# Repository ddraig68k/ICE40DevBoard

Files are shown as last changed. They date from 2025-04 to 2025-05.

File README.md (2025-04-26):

# Lattice ICE40HX8K Development board

Intended as a development system for a software CPU computer design.

Includes:
16-bit VGA video
Audio output
512KB SRAM
FT232H interface for UART and device programming
MicroSD card
PS/2 Keyboard and mouse
Sega Megadrive joystick interface
3 push buttons
3 user LEDs
2 seven segment LEDs

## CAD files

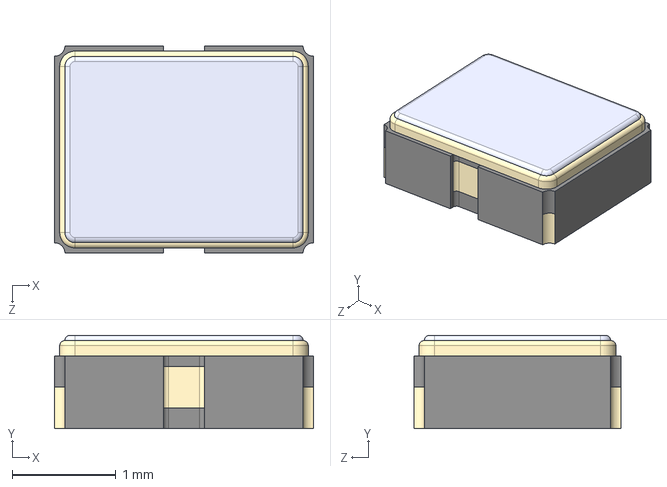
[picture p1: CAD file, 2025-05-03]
CAD/ECS-2520MV-120-BL-TR.STEP
2.50 x 0.9 x 2.00 mm

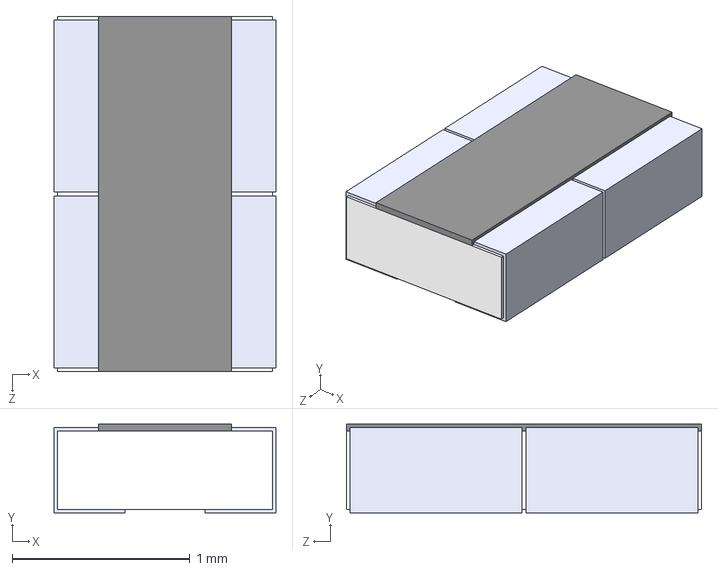
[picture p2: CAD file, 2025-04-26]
CAD/EXB-S8V391J.stp
1.25 x 0.5 x 2.00 mm

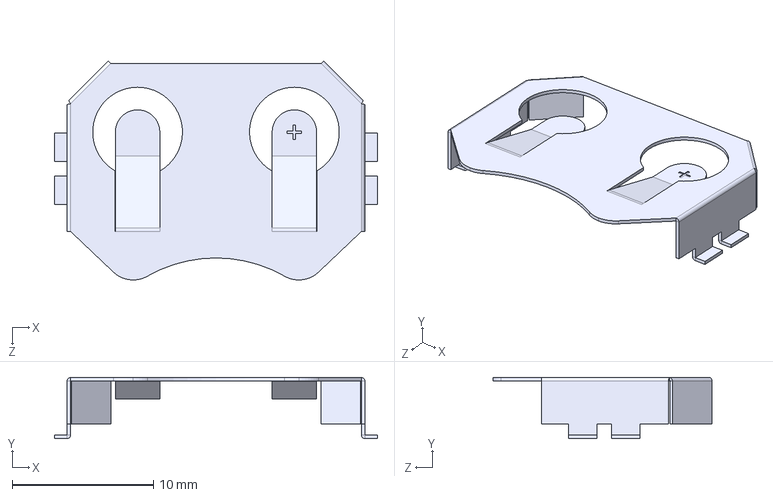
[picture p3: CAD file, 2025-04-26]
CAD/BAT-HLD-001.step
22.9 x 4.32 x 15.5 mm

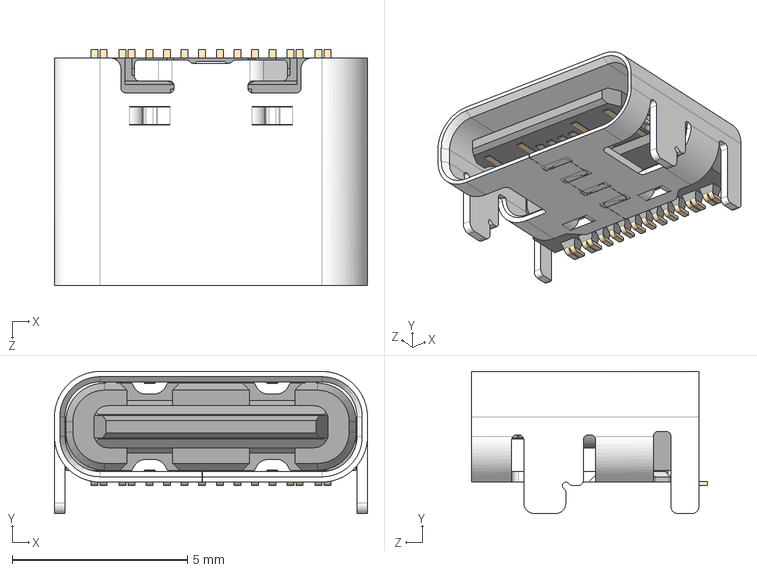
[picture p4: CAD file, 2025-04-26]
CAD/USB4215-03-A_revA.STEP
8.94 x 4.06 x 6.75 mm
HSG_ASM_1

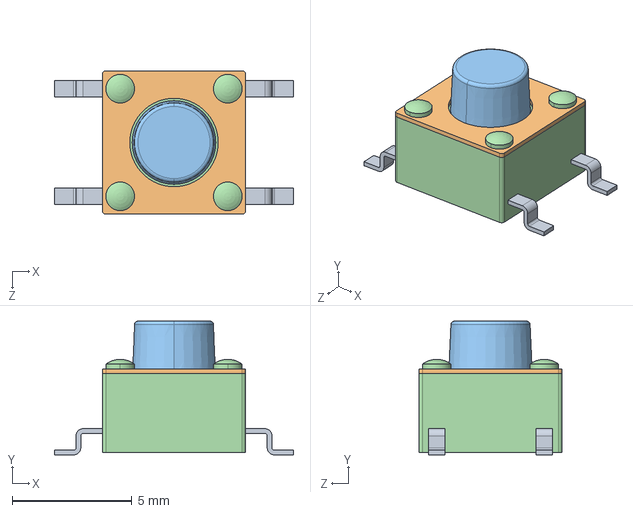
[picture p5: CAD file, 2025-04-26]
CAD/TS04-66-55-BK-100-SMT-TR.step
10.0 x 5.60 x 6.00 mm

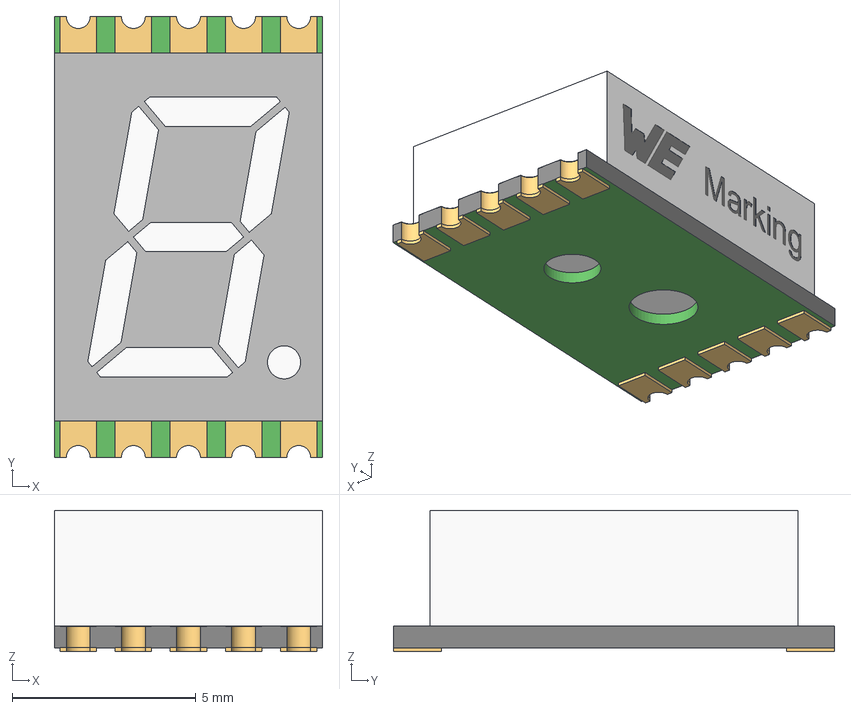
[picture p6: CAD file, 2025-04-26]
CAD/STP_157112x12x00+.stp
7.30 x 12.0 x 3.85 mm
PCB
Pins x 20
Chip

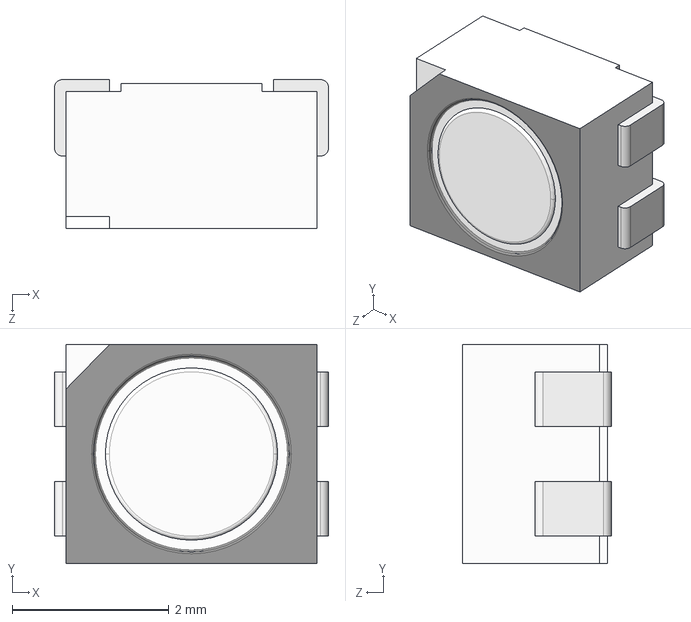
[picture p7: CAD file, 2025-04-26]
CAD/CLV1L-FKB-CJ1N1E1BB7B3B3.stp
3.50 x 2.80 x 1.90 mm

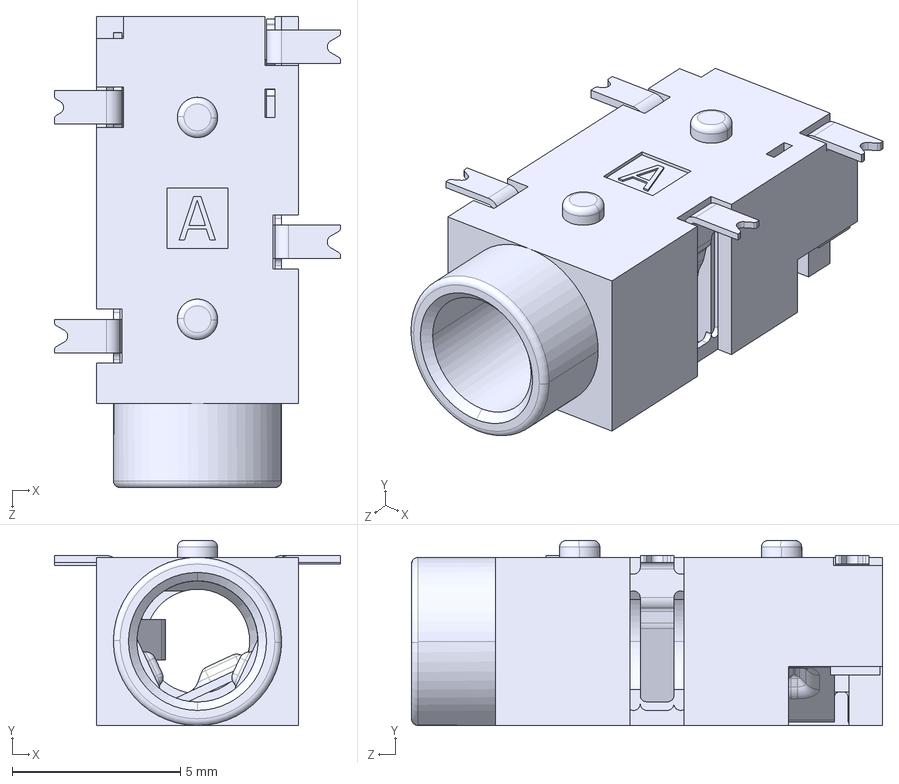
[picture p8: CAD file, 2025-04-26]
CAD/SJ2-35813B-SMT-TR.step
8.50 x 5.50 x 14.0 mm

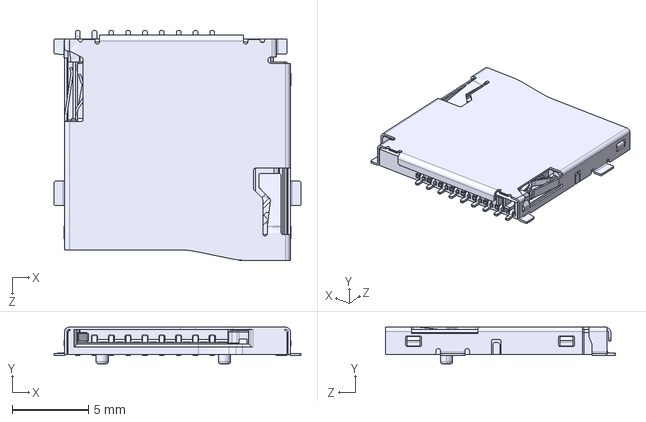
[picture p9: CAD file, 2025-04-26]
CAD/MSD-1-A.step
16.1 x 2.40 x 15.0 mm

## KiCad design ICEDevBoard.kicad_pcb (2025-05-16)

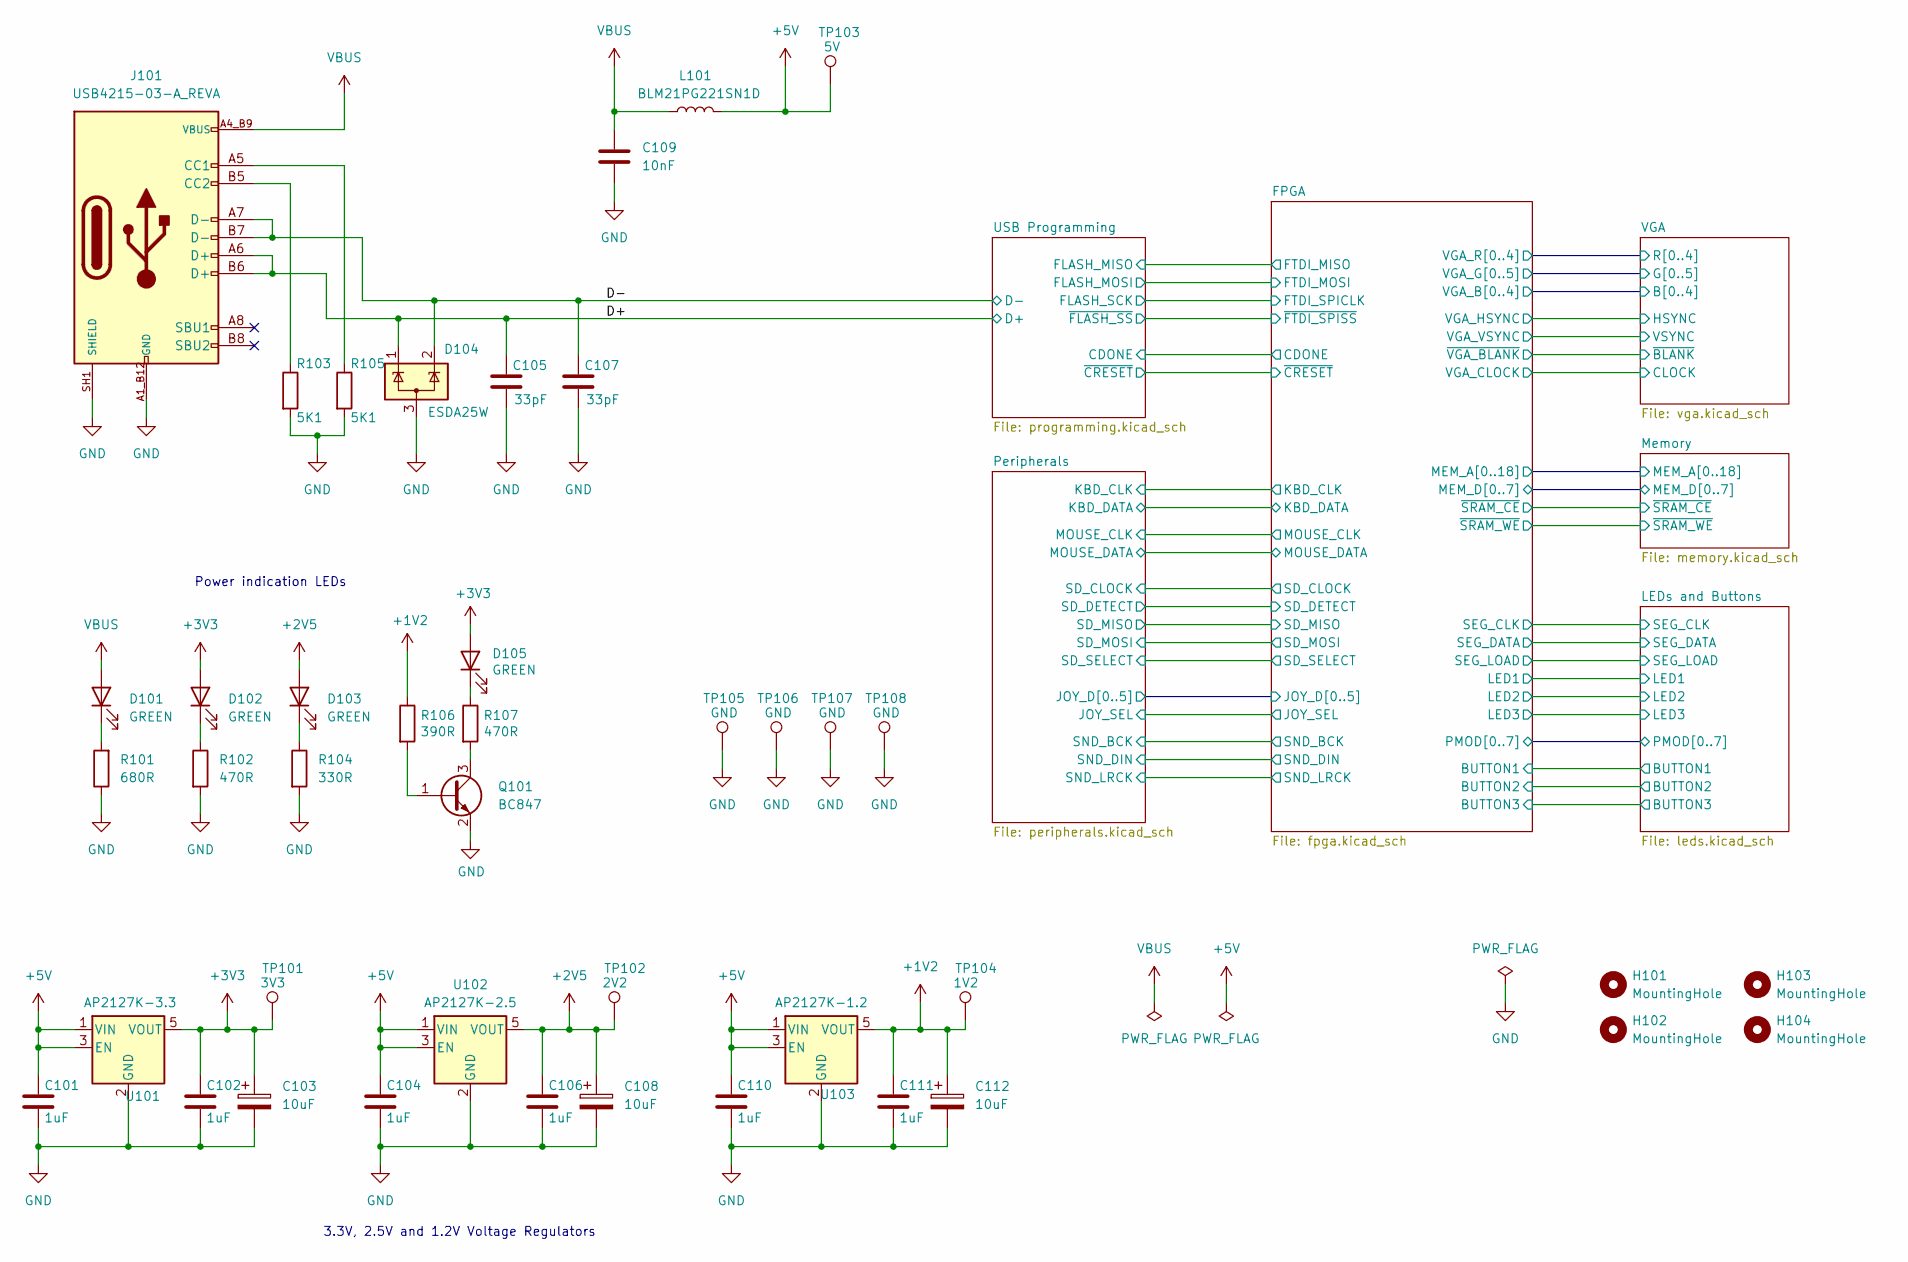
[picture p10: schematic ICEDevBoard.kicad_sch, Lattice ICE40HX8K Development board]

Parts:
C101, C102, C104, C106, C110, C111: 1uF; C_0805_2012Metric
C103, C108, C112: 10uF; CP_Elec_4x5.3
C105, C107: 33pF; C_0805_2012Metric
C109: 10nF; C_0805_2012Metric
D101, D102, D103, D105: GREEN; LED_1206_3216Metric
D104: ESDA25W; SOT-23-3
H101, H102, H103, H104: MountingHole; MountingHole_4.3mm_M4
J101: USB4215-03-A_REVA; GCT_USB4215-03-A_REVA; PARTREV A
L101: BLM21PG221SN1D; L_1206_3216Metric
Q101: BC847; SOT-23
R101: 680R; R_0805_2012Metric
R102, R107: 470R; R_0805_2012Metric
R103, R105: 5K1; R_0805_2012Metric
R104: 330R; R_0805_2012Metric
R106: 390R; R_0805_2012Metric
TP101: 3V3; TestPoint_Pad_D1.0mm
TP102: 2V2; TestPoint_Pad_D1.0mm
TP103: 5V; TestPoint_Pad_D1.0mm
TP104: 1V2; TestPoint_Pad_D1.0mm
TP105, TP106, TP107, TP108: GND; TestPoint_THTPad_D1.0mm_Drill0.5mm
U101: AP2127K-3.3; SOT-23-5
U102: AP2127K-2.5; SOT-23-5
U103: AP2127K-1.2; SOT-23-5

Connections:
+1V2: C111.1, C112.1, R106.1, TP104.1, U103.5 (VOUT); also elsewhere on the board
+2V5: C106.1, C108.1, D103.2 (A), TP102.1, U102.5 (VOUT); also elsewhere on the board
+3V3: C102.1, C103.1, D102.2 (A), D105.2 (A), TP101.1, U101.5 (VOUT); also elsewhere on the board
+5V: C101.1, C104.1, C110.1, L101.2, TP103.1, U101.1 (VIN), U101.3 (EN), U102.1 (VIN), U102.3 (EN), U103.1 (VIN), U103.3 (EN); also elsewhere on the board
/D+: C105.1, D104.1 (K), J101.A6 (D+), J101.B6 (D+); also elsewhere on the board
/D-: C107.1, D104.2 (K), J101.A7 (D-), J101.B7 (D-); also elsewhere on the board
GND: C101.2, C102.2, C103.2, C104.2, C105.2, C106.2, C107.2, C108.2, C109.2, C110.2, C111.2, C112.2, D104.3 (A), J101.A1_B12 (GND), J101.B1_A12 (GND), J101.SH1 (SHIELD), J101.SH2 (SHIELD), J101.SH3 (SHIELD), J101.SH4 (SHIELD), Q101.2 (E), R101.1, R102.2, R103.2, R104.2, R105.2, TP105.1, TP106.1, TP107.1, TP108.1, U101.2 (GND), U102.2 (GND), U103.2 (GND); also elsewhere on the board
unnamed: D101.1 (K), R101.2
unnamed: D102.1 (K), R102.1
unnamed: D103.1 (K), R104.1
unnamed: D105.1 (K), R107.1
unnamed: J101.A5 (CC1), R105.1
unnamed: J101.B5 (CC2), R103.1
unnamed: Q101.1 (B), R106.2
unnamed: Q101.3 (C), R107.2
VBUS: C109.1, D101.2 (A), J101.A4_B9 (VBUS), J101.B4_A9 (VBUS), L101.1

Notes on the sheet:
Power indication LEDs
3.3V, 2.5V and 1.2V Voltage Regulators

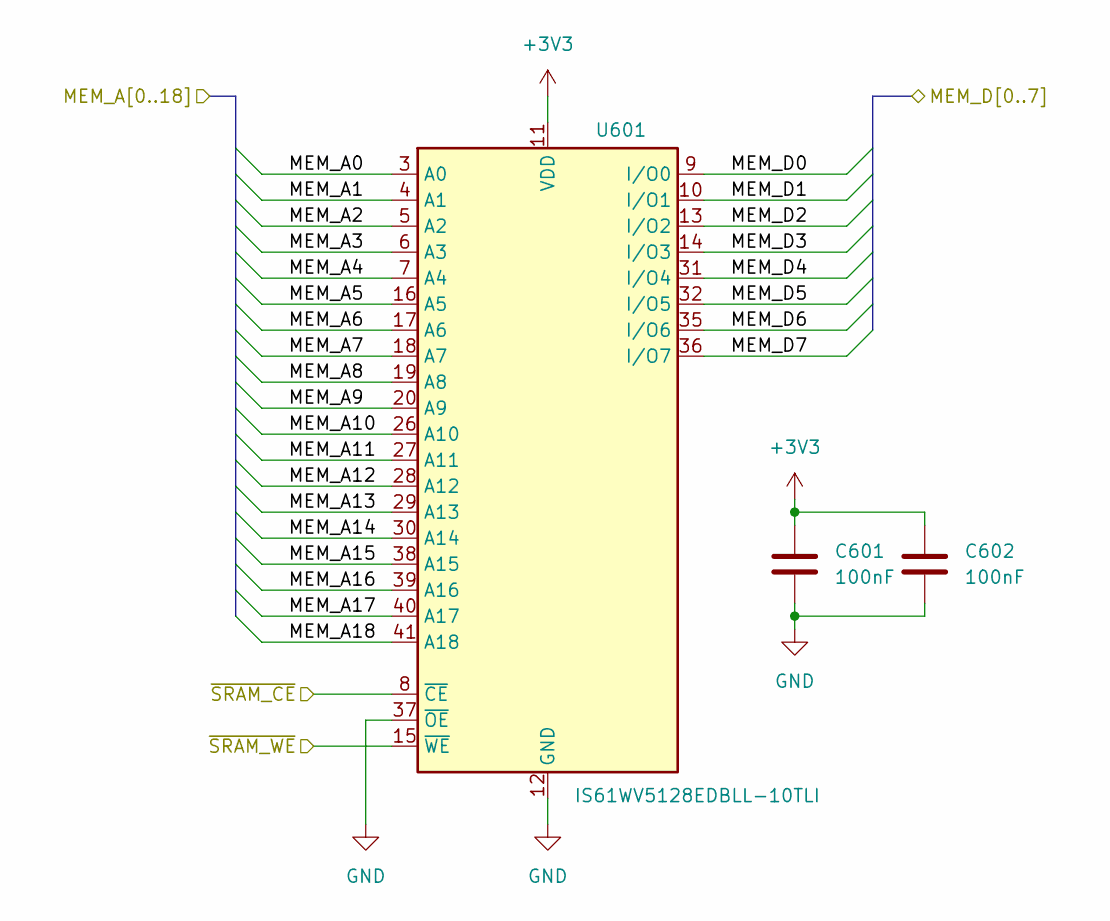
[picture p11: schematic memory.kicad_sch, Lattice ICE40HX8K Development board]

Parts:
C601, C602: 100nF; C_0805_2012Metric
U601: IS61WV5128EDBLL-10TLI; TSOP-II-44_10.16x18.41mm_P0.8mm

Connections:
+3V3: C601.1, C602.1, U601.11 (VDD), U601.33 (VDD); also elsewhere on the board
/FPGA/MEM_A0: U601.3 (A0); also elsewhere on the board
/FPGA/MEM_A1: U601.4 (A1); also elsewhere on the board
/FPGA/MEM_A2: U601.5 (A2); also elsewhere on the board
/FPGA/MEM_A3: U601.6 (A3); also elsewhere on the board
/FPGA/MEM_A4: U601.7 (A4); also elsewhere on the board
/FPGA/MEM_A5: U601.16 (A5); also elsewhere on the board
/FPGA/MEM_A6: U601.17 (A6); also elsewhere on the board
/FPGA/MEM_A7: U601.18 (A7); also elsewhere on the board
/FPGA/MEM_A8: U601.19 (A8); also elsewhere on the board
/FPGA/MEM_A9: U601.20 (A9); also elsewhere on the board
/FPGA/MEM_A10: U601.26 (A10); also elsewhere on the board
/FPGA/MEM_A11: U601.27 (A11); also elsewhere on the board
/FPGA/MEM_A12: U601.28 (A12); also elsewhere on the board
/FPGA/MEM_A13: U601.29 (A13); also elsewhere on the board
/FPGA/MEM_A14: U601.30 (A14); also elsewhere on the board
/FPGA/MEM_A15: U601.38 (A15); also elsewhere on the board
/FPGA/MEM_A16: U601.39 (A16); also elsewhere on the board
/FPGA/MEM_A17: U601.40 (A17); also elsewhere on the board
/FPGA/MEM_A18: U601.41 (A18); also elsewhere on the board
/FPGA/MEM_D0: U601.9 (I/O0); also elsewhere on the board
/FPGA/MEM_D1: U601.10 (I/O1); also elsewhere on the board
/FPGA/MEM_D2: U601.13 (I/O2); also elsewhere on the board
/FPGA/MEM_D3: U601.14 (I/O3); also elsewhere on the board
/FPGA/MEM_D4: U601.31 (I/O4); also elsewhere on the board
/FPGA/MEM_D5: U601.32 (I/O5); also elsewhere on the board
/FPGA/MEM_D6: U601.35 (I/O6); also elsewhere on the board
/FPGA/MEM_D7: U601.36 (I/O7); also elsewhere on the board
/FPGA/~SRAM_CE: U601.8 (~CE); also elsewhere on the board
/FPGA/~SRAM_WE: U601.15 (~WE); also elsewhere on the board
GND: C601.2, C602.2, U601.12 (GND), U601.34 (GND), U601.37 (~OE); also elsewhere on the board

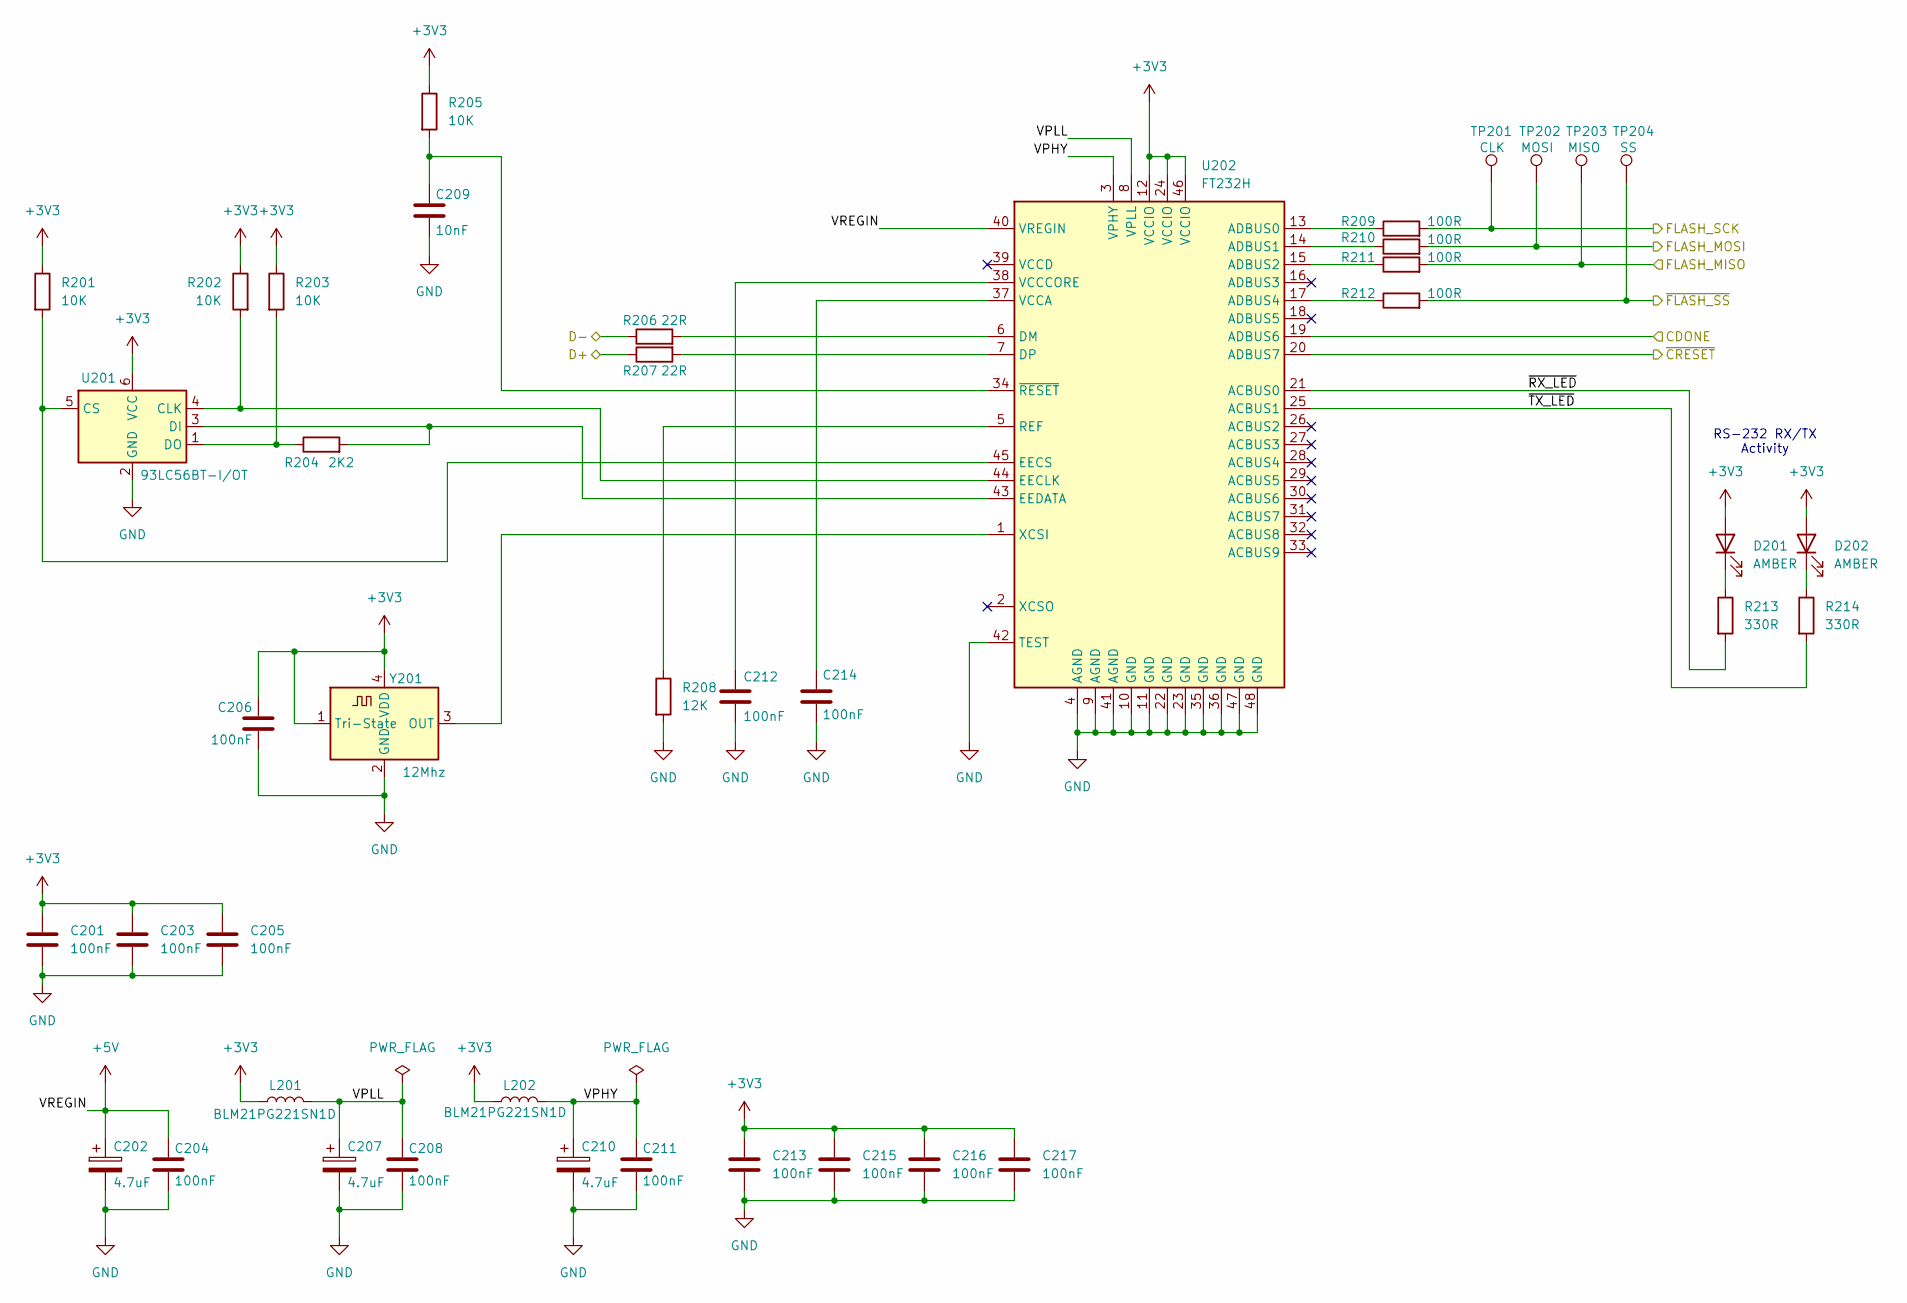
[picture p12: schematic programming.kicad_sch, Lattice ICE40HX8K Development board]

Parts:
C201, C203, C204, C205, C206, C208, C211, C212, C213, C214, C215, C216, C217: 100nF; C_0805_2012Metric
C202, C207, C210: 4.7uF; CP_Elec_4x5.3
C209: 10nF; C_0805_2012Metric
D201, D202: AMBER; LED_1206_3216Metric
L201, L202: BLM21PG221SN1D; L_1206_3216Metric
R201, R202, R203, R205: 10K; R_0805_2012Metric
R204: 2K2; R_0805_2012Metric
R206, R207: 22R; R_0805_2012Metric
R208: 12K; R_0805_2012Metric
R209, R210, R211, R212: 100R; R_0805_2012Metric
R213, R214: 330R; R_0805_2012Metric
TP201: CLK; TestPoint_Pad_D1.0mm
TP202: MOSI; TestPoint_Pad_D1.0mm
TP203: MISO; TestPoint_Pad_D1.0mm
TP204: SS; TestPoint_Pad_D1.0mm
U201: 93LC56BT-I/OT; SOT-23-6
U202: FT232H; LQFP-48_7x7mm_P0.5mm
Y201: 12Mhz; Oscillator_SMD_ECS_2520MV-xxx-xx-4Pin_2.5x2.0mm

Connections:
+3V3: C201.1, C203.1, C205.1, C206.1, C213.1, C215.1, C216.1, C217.1, D201.2 (A), D202.2 (A), L201.1, L202.1, R201.1, R202.1, R203.1, R205.1, U201.6 (VCC), U202.12 (VCCIO), U202.24 (VCCIO), U202.46 (VCCIO), Y201.1 (Tri-State), Y201.4 (VDD); also elsewhere on the board
+5V: C202.1, C204.1, U202.40 (VREGIN); also elsewhere on the board
/D+: R207.1; also elsewhere on the board
/D-: R206.1; also elsewhere on the board
/FPGA/CDONE: U202.19 (ADBUS6); also elsewhere on the board
/FPGA/FTDI_MISO: R211.2, TP203.1; also elsewhere on the board
/FPGA/FTDI_MOSI: R210.2, TP202.1; also elsewhere on the board
/FPGA/FTDI_SPICLK: R209.2, TP201.1; also elsewhere on the board
/FPGA/~CRESET: U202.20 (ADBUS7); also elsewhere on the board
/FPGA/~FTDI_SPISS: R212.2, TP204.1; also elsewhere on the board
/USB Programming/VPHY: C210.1, C211.1, L202.2, U202.3 (VPHY)
/USB Programming/VPLL: C207.1, C208.1, L201.2, U202.8 (VPLL)
/USB Programming/~RX_LED: R213.2, U202.21 (ACBUS0)
/USB Programming/~TX_LED: R214.2, U202.25 (ACBUS1)
GND: C201.2, C202.2, C203.2, C204.2, C205.2, C206.2, C207.2, C208.2, C209.2, C210.2, C211.2, C212.2, C213.2, C214.2, C215.2, C216.2, C217.2, R208.2, U201.2 (GND), U202.4 (AGND), U202.9 (AGND), U202.10 (GND), U202.11 (GND), U202.22 (GND), U202.23 (GND), U202.35 (GND), U202.36 (GND), U202.41 (AGND), U202.42 (TEST), U202.47 (GND), U202.48 (GND), Y201.2 (GND); also elsewhere on the board
unnamed: D201.1 (K), R213.1
unnamed: D202.1 (K), R214.1
unnamed: R202.2, U201.4 (CLK), U202.44 (EECLK)
unnamed: R201.2, U201.5 (CS), U202.45 (EECS)
unnamed: R204.2, U201.3 (DI), U202.43 (EEDATA)
unnamed: R203.2, R204.1, U201.1 (DO)
unnamed: R209.1, U202.13 (ADBUS0)
unnamed: R210.1, U202.14 (ADBUS1)
unnamed: R211.1, U202.15 (ADBUS2)
unnamed: R212.1, U202.17 (ADBUS4)
unnamed: R206.2, U202.6 (DM)
unnamed: R207.2, U202.7 (DP)
unnamed: R208.1, U202.5 (REF)
unnamed: C214.1, U202.37 (VCCA)
unnamed: C212.1, U202.38 (VCCCORE)
unnamed: U202.1 (XCSI), Y201.3 (OUT)
unnamed: C209.1, R205.2, U202.34 (~RESET)

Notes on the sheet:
RS-232 RX/TX Activity

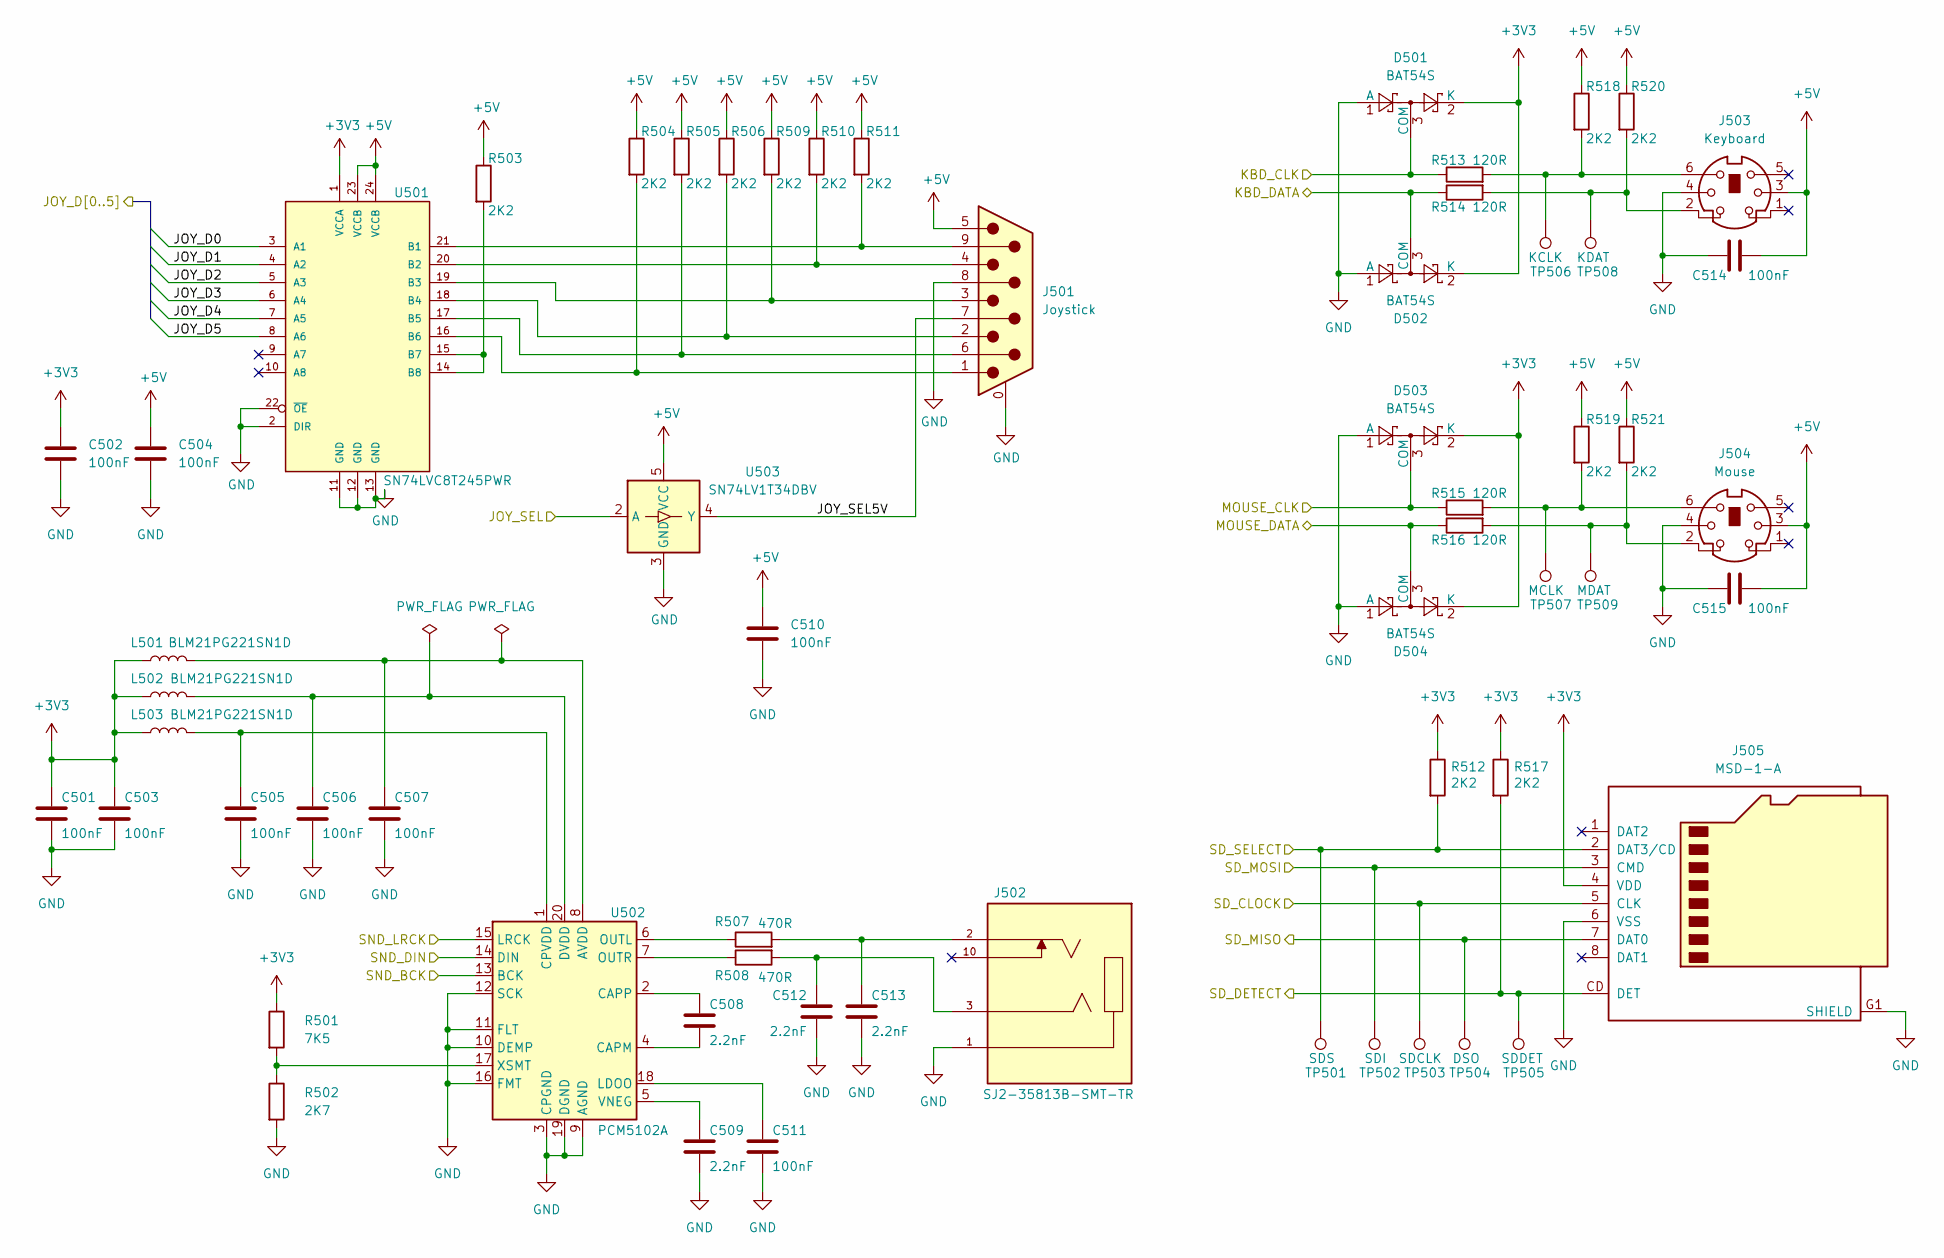
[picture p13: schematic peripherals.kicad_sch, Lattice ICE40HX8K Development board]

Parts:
C501, C502, C503, C504, C505, C506, C507, C510, C511, C514, C515: 100nF; C_0805_2012Metric
C508, C509, C512, C513: 2.2nF; C_0805_2012Metric
D501, D502, D503, D504: BAT54S; SOT-23
J501: Joystick; DSUB-9_Pins_Horizontal_P2.77x2.84mm_EdgePinOffset4.94mm_Hou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
J502: SJ2-35813B-SMT-TR; CUI_SJ2-35813B-SMT-TR
J503: Keyboard; MINI-DIN-6-FULL-SHIELD
J504: Mouse; MINI-DIN-6-FULL-SHIELD
J505: MSD-1-A; CUI_MSD-1-A
L501, L502, L503: BLM21PG221SN1D; L_1206_3216Metric
R501: 7K5; R_0805_2012Metric
R502: 2K7; R_0805_2012Metric
R503, R504, R505, R506, R509, R510, R511, R512, R517, R518, R519, R520, R521: 2K2; R_0805_2012Metric
R507, R508: 470R; R_0805_2012Metric
R513, R514, R515, R516: 120R; R_0805_2012Metric
TP501: SDS; TestPoint_Pad_D1.0mm
TP502: SDI; TestPoint_Pad_D1.0mm
TP503: SDCLK; TestPoint_Pad_D1.0mm
TP504: DSO; TestPoint_Pad_D1.0mm
TP505: SDDET; TestPoint_Pad_D1.0mm
TP506: KCLK; TestPoint_Pad_D1.0mm
TP507: MCLK; TestPoint_Pad_D1.0mm
TP508: KDAT; TestPoint_Pad_D1.0mm
TP509: MDAT; TestPoint_Pad_D1.0mm
U501: SN74LVC8T245PWR; SOP65P640X120-24N
U502: PCM5102A; TSSOP-20_4.4x6.5mm_P0.65mm
U503: SN74LV1T34DBV; SOT-23-5

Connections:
+3V3: C501.1, C502.1, C503.1, D501.2 (K), D502.2 (K), D503.2 (K), D504.2 (K), J505.4 (VDD), L501.1, L502.1, L503.1, R501.1, R512.1, R517.1, U501.1 (VCCA); also elsewhere on the board
+5V: C504.1, C510.1, C514.2, C515.2, J501.5, J503.3, J504.3, R503.1, R504.1, R505.1, R506.1, R509.1, R510.1, R511.1, R518.1, R519.1, R520.1, R521.1, U501.23 (VCCB), U501.24 (VCCB), U503.5 (VCC); also elsewhere on the board
/FPGA/JOY_D0: U501.3 (A1); also elsewhere on the board
/FPGA/JOY_D1: U501.4 (A2); also elsewhere on the board
/FPGA/JOY_D2: U501.5 (A3); also elsewhere on the board
/FPGA/JOY_D3: U501.6 (A4); also elsewhere on the board
/FPGA/JOY_D4: U501.7 (A5); also elsewhere on the board
/FPGA/JOY_D5: U501.8 (A6); also elsewhere on the board
/FPGA/JOY_SEL: U503.2 (A); also elsewhere on the board
/FPGA/KBD_CLK: D501.3 (COM), R513.1; also elsewhere on the board
/FPGA/KBD_DATA: D502.3 (COM), R514.1; also elsewhere on the board
/FPGA/MOUSE_CLK: D503.3 (COM), R515.1; also elsewhere on the board
/FPGA/MOUSE_DATA: D504.3 (COM), R516.1; also elsewhere on the board
/FPGA/SD_CLOCK: J505.5 (CLK), TP503.1; also elsewhere on the board
/FPGA/SD_DETECT: J505.CD (DET), R517.2, TP505.1; also elsewhere on the board
/FPGA/SD_MISO: J505.7 (DAT0), TP504.1; also elsewhere on the board
/FPGA/SD_MOSI: J505.3 (CMD), TP502.1; also elsewhere on the board
/FPGA/SD_SELECT: J505.2 (DAT3/CD), R512.2, TP501.1; also elsewhere on the board
/FPGA/SND_BCK: U502.13 (BCK); also elsewhere on the board
/FPGA/SND_DIN: U502.14 (DIN); also elsewhere on the board
/FPGA/SND_LRCK: U502.15 (LRCK); also elsewhere on the board
/Peripherals/JOY_SEL5V: J501.7, U503.4 (Y)
GND: C501.2, C502.2, C503.2, C504.2, C505.2, C506.2, C507.2, C509.2, C510.2, C511.2, C512.2, C513.2, C514.1, C515.1, D501.1 (A), D502.1 (A), D503.1 (A), D504.1 (A), J501.0 (PAD), J501.8, J502.1, J503.4, J504.4, J505.6 (VSS), J505.G1 (SHIELD), J505.G2 (SHIELD), J505.G3 (SHIELD), J505.G4 (SHIELD), R502.2, U501.2 (DIR), U501.11 (GND), U501.12 (GND), U501.13 (GND), U501.22 (~OE), U502.3 (CPGND), U502.9 (AGND), U502.10 (DEMP), U502.11 (FLT), U502.12 (SCK), U502.16 (FMT), U502.19 (DGND), U503.3 (GND); also elsewhere on the board
unnamed: C512.1, J502.3, R508.2
unnamed: C513.1, J502.2, R507.2
unnamed: J503.2, R514.2, R520.2, TP508.1
unnamed: J503.6, R513.2, R518.2, TP506.1
unnamed: J504.2, R516.2, R521.2, TP509.1
unnamed: J504.6, R515.2, R519.2, TP507.1
unnamed: J501.9, R511.2, U501.21 (B1)
unnamed: J501.4, R510.2, U501.20 (B2)
unnamed: J501.3, R509.2, U501.19 (B3)
unnamed: J501.2, R506.2, U501.18 (B4)
unnamed: J501.6, R505.2, U501.17 (B5)
unnamed: J501.1, R504.2, U501.16 (B6)
unnamed: R503.2, U501.14 (B8), U501.15 (B7)
unnamed: C507.1, L501.2, U502.8 (AVDD)
unnamed: C508.2, U502.4 (CAPM)
unnamed: C508.1, U502.2 (CAPP)
unnamed: C505.1, L503.2, U502.1 (CPVDD)
unnamed: C506.1, L502.2, U502.20 (DVDD)
unnamed: C511.1, U502.18 (LDOO)
unnamed: R507.1, U502.6 (OUTL)
unnamed: R508.1, U502.7 (OUTR)
unnamed: C509.1, U502.5 (VNEG)
unnamed: R501.2, R502.1, U502.17 (XSMT)

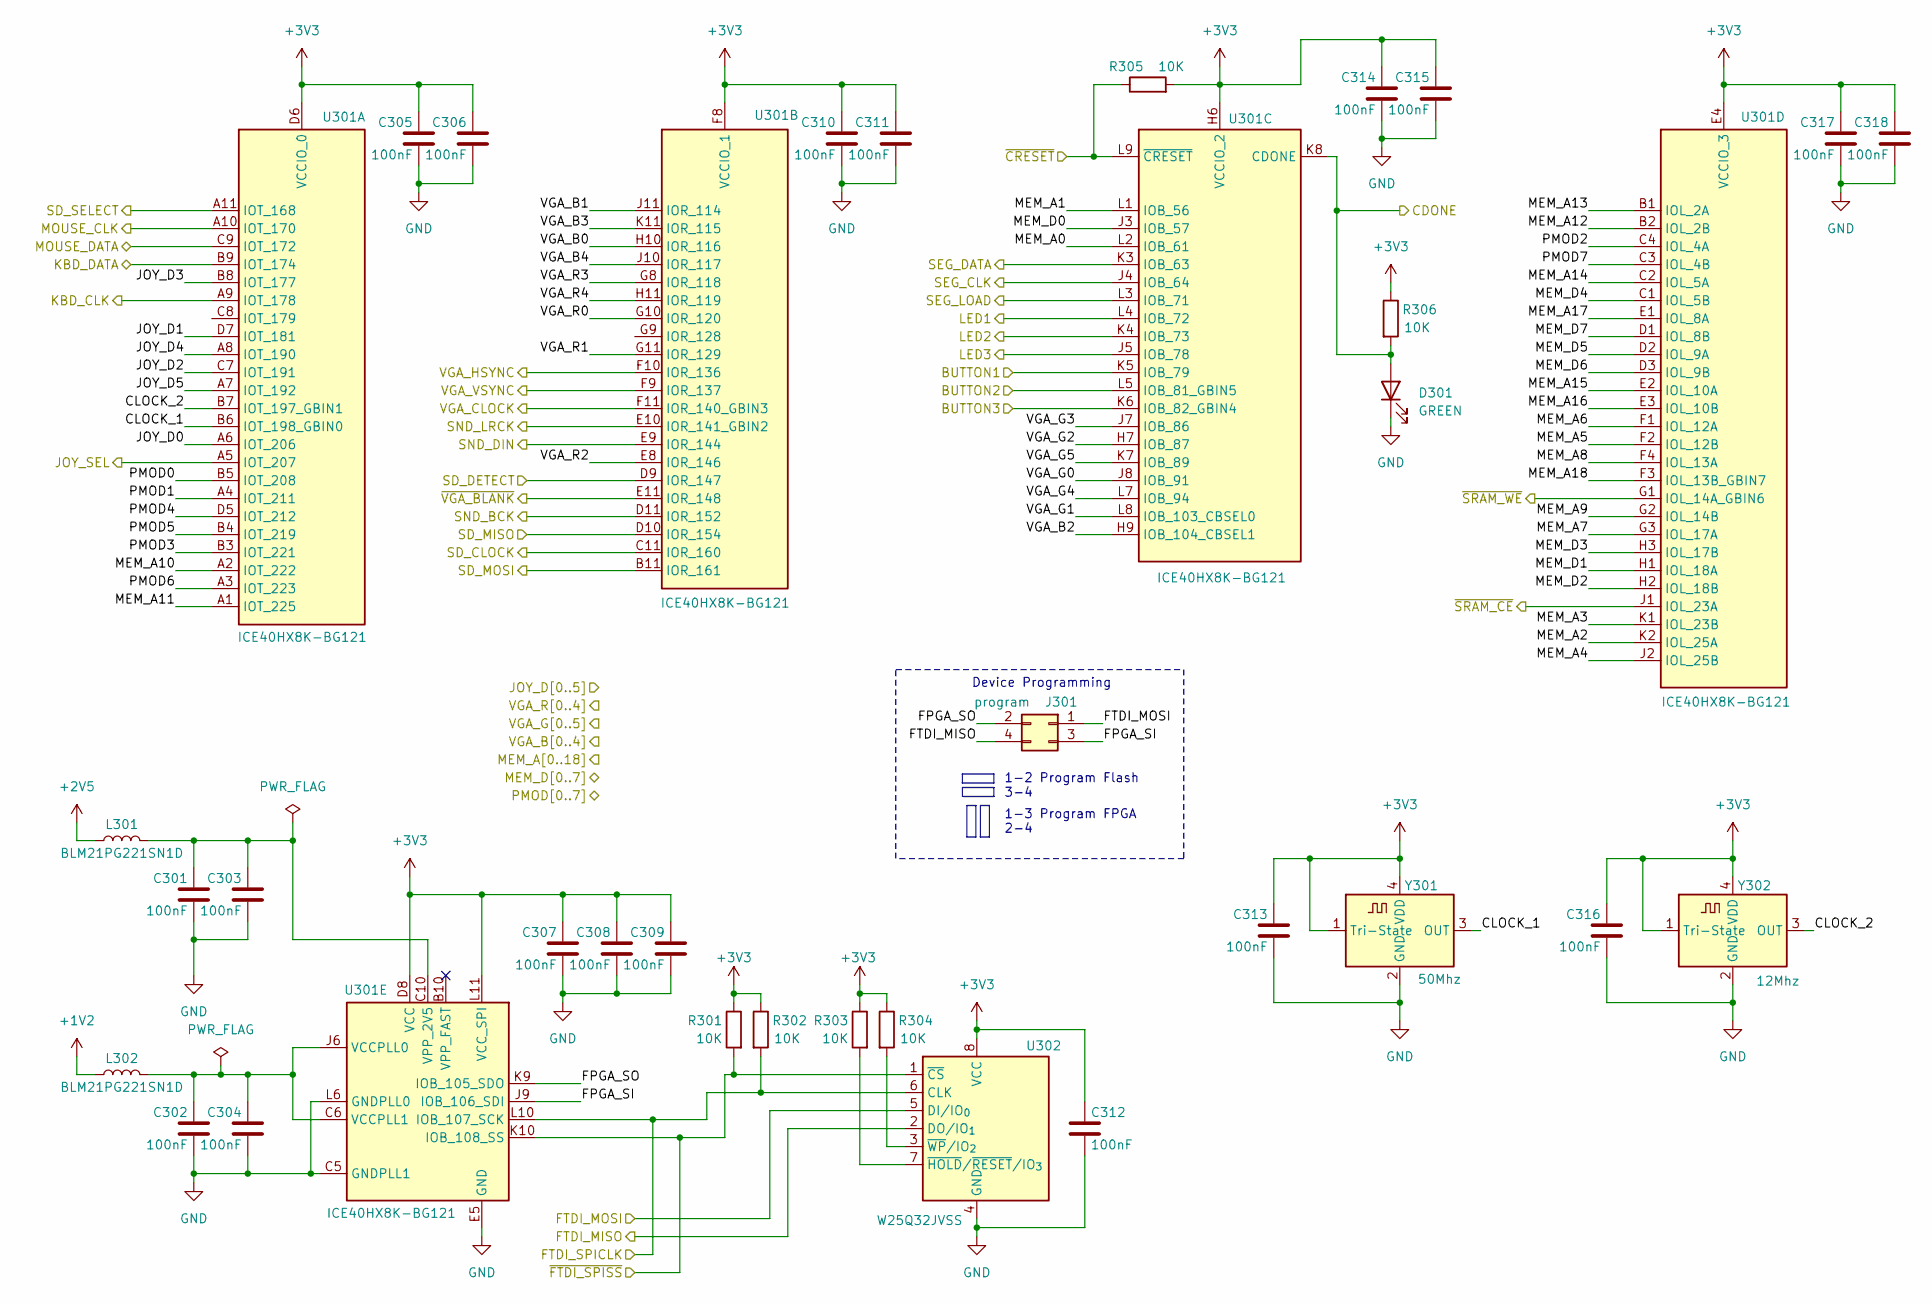
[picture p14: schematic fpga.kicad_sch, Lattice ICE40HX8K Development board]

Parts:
C301, C302, C303, C304, C305, C306, C307, C308, C309, C310, C311, C312, C313, C314, C315, C316, C317, C318: 100nF; C_0603_1608Metric
D301: GREEN; LED_1206_3216Metric
J301: program; PinSocket_2x02_P2.54mm_Vertical
L301, L302: BLM21PG221SN1D; L_1206_3216Metric
R301, R302, R303, R304, R305, R306: 10K; R_0805_2012Metric
U301: ICE40HX8K-BG121; BGA-121_9.0x9.0mm_Layout11x11_P0.8mm_Ball0.4mm_Pad0.35mm_NS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
U302: W25Q32JVSS; SOIC-8_5.3x5.3mm_P1.27mm
Y301: 50Mhz; Oscillator_SMD_ECS_2520MV-xxx-xx-4Pin_2.5x2.0mm
Y302: 12Mhz; Oscillator_SMD_ECS_2520MV-xxx-xx-4Pin_2.5x2.0mm

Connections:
+1V2: L302.1; also elsewhere on the board
+2V5: L301.1; also elsewhere on the board
+3V3: C305.1, C306.1, C307.1, C308.1, C309.1, C310.1, C311.1, C312.1, C313.1, C314.1, C315.1, C316.1, C317.1, C318.1, R301.1, R302.1, R303.1, R304.1, R305.2, R306.1, U301.D4 (VCC), U301.D6 (VCCIO_0), U301.D8 (VCC), U301.E4 (VCCIO_3), U301.F8 (VCCIO_1), U301.G4 (VCCIO_3), U301.H4 (VCC), U301.H6 (VCCIO_2), U301.H8 (VCC), U301.L11 (VCC_SPI), U302.8 (VCC), Y301.1 (Tri-State), Y301.4 (VDD), Y302.1 (Tri-State), Y302.4 (VDD); also elsewhere on the board
/FPGA/BUTTON1: U301.K5 (IOB_79); also elsewhere on the board
/FPGA/BUTTON2: U301.L5 (IOB_81_GBIN5); also elsewhere on the board
/FPGA/BUTTON3: U301.K6 (IOB_82_GBIN4); also elsewhere on the board
/FPGA/CDONE: D301.2 (A), R306.2, U301.K8 (CDONE); also elsewhere on the board
/FPGA/CLOCK_1: U301.B6 (IOT_198_GBIN0), Y301.3 (OUT)
/FPGA/CLOCK_2: U301.B7 (IOT_197_GBIN1), Y302.3 (OUT)
/FPGA/FPGA_SI: J301.3, U301.J9 (IOB_106_SDI)
/FPGA/FPGA_SO: J301.2, U301.K9 (IOB_105_SDO)
/FPGA/FTDI_MISO: J301.4, U302.2 (DO/IO_{1}); also elsewhere on the board
/FPGA/FTDI_MOSI: J301.1, U302.5 (DI/IO_{0}); also elsewhere on the board
/FPGA/FTDI_SPICLK: R302.2, U301.L10 (IOB_107_SCK), U302.6 (CLK); also elsewhere on the board
/FPGA/JOY_D0: U301.A6 (IOT_206); also elsewhere on the board
/FPGA/JOY_D1: U301.D7 (IOT_181); also elsewhere on the board
/FPGA/JOY_D2: U301.C7 (IOT_191); also elsewhere on the board
/FPGA/JOY_D3: U301.B8 (IOT_177); also elsewhere on the board
/FPGA/JOY_D4: U301.A8 (IOT_190); also elsewhere on the board
/FPGA/JOY_D5: U301.A7 (IOT_192); also elsewhere on the board
/FPGA/JOY_SEL: U301.A5 (IOT_207); also elsewhere on the board
/FPGA/KBD_CLK: U301.A9 (IOT_178); also elsewhere on the board
/FPGA/KBD_DATA: U301.B9 (IOT_174); also elsewhere on the board
/FPGA/LED1: U301.L4 (IOB_72); also elsewhere on the board
/FPGA/LED2: U301.K4 (IOB_73); also elsewhere on the board
/FPGA/LED3: U301.J5 (IOB_78); also elsewhere on the board
/FPGA/MEM_A0: U301.L2 (IOB_61); also elsewhere on the board
/FPGA/MEM_A1: U301.L1 (IOB_56); also elsewhere on the board
/FPGA/MEM_A2: U301.K2 (IOL_25A); also elsewhere on the board
/FPGA/MEM_A3: U301.K1 (IOL_23B); also elsewhere on the board
/FPGA/MEM_A4: U301.J2 (IOL_25B); also elsewhere on the board
/FPGA/MEM_A5: U301.F2 (IOL_12B); also elsewhere on the board
/FPGA/MEM_A6: U301.F1 (IOL_12A); also elsewhere on the board
/FPGA/MEM_A7: U301.G3 (IOL_17A); also elsewhere on the board
/FPGA/MEM_A8: U301.F4 (IOL_13A); also elsewhere on the board
/FPGA/MEM_A9: U301.G2 (IOL_14B); also elsewhere on the board
/FPGA/MEM_A10: U301.A2 (IOT_222); also elsewhere on the board
/FPGA/MEM_A11: U301.A1 (IOT_225); also elsewhere on the board
/FPGA/MEM_A12: U301.B2 (IOL_2B); also elsewhere on the board
/FPGA/MEM_A13: U301.B1 (IOL_2A); also elsewhere on the board
/FPGA/MEM_A14: U301.C2 (IOL_5A); also elsewhere on the board
/FPGA/MEM_A15: U301.E2 (IOL_10A); also elsewhere on the board
/FPGA/MEM_A16: U301.E3 (IOL_10B); also elsewhere on the board
/FPGA/MEM_A17: U301.E1 (IOL_8A); also elsewhere on the board
/FPGA/MEM_A18: U301.F3 (IOL_13B_GBIN7); also elsewhere on the board
/FPGA/MEM_D0: U301.J3 (IOB_57); also elsewhere on the board
/FPGA/MEM_D1: U301.H1 (IOL_18A); also elsewhere on the board
/FPGA/MEM_D2: U301.H2 (IOL_18B); also elsewhere on the board
/FPGA/MEM_D3: U301.H3 (IOL_17B); also elsewhere on the board
/FPGA/MEM_D4: U301.C1 (IOL_5B); also elsewhere on the board
/FPGA/MEM_D5: U301.D2 (IOL_9A); also elsewhere on the board
/FPGA/MEM_D6: U301.D3 (IOL_9B); also elsewhere on the board
/FPGA/MEM_D7: U301.D1 (IOL_8B); also elsewhere on the board
/FPGA/MOUSE_CLK: U301.A10 (IOT_170); also elsewhere on the board
/FPGA/MOUSE_DATA: U301.C9 (IOT_172); also elsewhere on the board
/FPGA/PMOD0: U301.B5 (IOT_208); also elsewhere on the board
/FPGA/PMOD1: U301.A4 (IOT_211); also elsewhere on the board
/FPGA/PMOD2: U301.C4 (IOL_4A); also elsewhere on the board
/FPGA/PMOD3: U301.B3 (IOT_221); also elsewhere on the board
/FPGA/PMOD4: U301.D5 (IOT_212); also elsewhere on the board
/FPGA/PMOD5: U301.B4 (IOT_219); also elsewhere on the board
/FPGA/PMOD6: U301.A3 (IOT_223); also elsewhere on the board
/FPGA/PMOD7: U301.C3 (IOL_4B); also elsewhere on the board
/FPGA/SD_CLOCK: U301.C11 (IOR_160); also elsewhere on the board
/FPGA/SD_DETECT: U301.D9 (IOR_147); also elsewhere on the board
/FPGA/SD_MISO: U301.D10 (IOR_154); also elsewhere on the board
/FPGA/SD_MOSI: U301.B11 (IOR_161); also elsewhere on the board
/FPGA/SD_SELECT: U301.A11 (IOT_168); also elsewhere on the board
/FPGA/SEG_CLK: U301.J4 (IOB_64); also elsewhere on the board
/FPGA/SEG_DATA: U301.K3 (IOB_63); also elsewhere on the board
/FPGA/SEG_LOAD: U301.L3 (IOB_71); also elsewhere on the board
/FPGA/SND_BCK: U301.D11 (IOR_152); also elsewhere on the board
/FPGA/SND_DIN: U301.E9 (IOR_144); also elsewhere on the board
/FPGA/SND_LRCK: U301.E10 (IOR_141_GBIN2); also elsewhere on the board
/FPGA/VGA_B0: U301.H10 (IOR_116); also elsewhere on the board
/FPGA/VGA_B1: U301.J11 (IOR_114); also elsewhere on the board
/FPGA/VGA_B2: U301.H9 (IOB_104_CBSEL1); also elsewhere on the board
/FPGA/VGA_B3: U301.K11 (IOR_115); also elsewhere on the board
/FPGA/VGA_B4: U301.J10 (IOR_117); also elsewhere on the board
/FPGA/VGA_CLOCK: U301.F11 (IOR_140_GBIN3); also elsewhere on the board
/FPGA/VGA_G0: U301.J8 (IOB_91); also elsewhere on the board
/FPGA/VGA_G1: U301.L8 (IOB_103_CBSEL0); also elsewhere on the board
/FPGA/VGA_G2: U301.H7 (IOB_87); also elsewhere on the board
/FPGA/VGA_G3: U301.J7 (IOB_86); also elsewhere on the board
/FPGA/VGA_G4: U301.L7 (IOB_94); also elsewhere on the board
/FPGA/VGA_G5: U301.K7 (IOB_89); also elsewhere on the board
/FPGA/VGA_HSYNC: U301.F10 (IOR_136); also elsewhere on the board
/FPGA/VGA_R0: U301.G10 (IOR_120); also elsewhere on the board
/FPGA/VGA_R1: U301.G11 (IOR_129); also elsewhere on the board
/FPGA/VGA_R2: U301.E8 (IOR_146); also elsewhere on the board
/FPGA/VGA_R3: U301.G8 (IOR_118); also elsewhere on the board
/FPGA/VGA_R4: U301.H11 (IOR_119); also elsewhere on the board
/FPGA/VGA_VSYNC: U301.F9 (IOR_137); also elsewhere on the board
/FPGA/~CRESET: R305.1, U301.L9 (~CRESET); also elsewhere on the board
/FPGA/~FTDI_SPISS: R301.2, U301.K10 (IOB_108_SS), U302.1 (~CS); also elsewhere on the board
/FPGA/~SRAM_CE: U301.J1 (IOL_23A); also elsewhere on the board
/FPGA/~SRAM_WE: U301.G1 (IOL_14A_GBIN6); also elsewhere on the board
/FPGA/~VGA_BLANK: U301.E11 (IOR_148); also elsewhere on the board
GND: C301.2, C302.2, C303.2, C304.2, C305.2, C306.2, C307.2, C308.2, C309.2, C310.2, C311.2, C312.2, C313.2, C314.2, C315.2, C316.2, C317.2, C318.2, D301.1 (K), U301.C5 (GNDPLL1), U301.E5 (GND), U301.E6 (GND), U301.E7 (GND), U301.F5 (GND), U301.F6 (GND), U301.F7 (GND), U301.G5 (GND), U301.G6 (GND), U301.G7 (GND), U301.H5 (GND), U301.L6 (GNDPLL0), U302.4 (GND), Y301.2 (GND), Y302.2 (GND); also elsewhere on the board
unnamed: C302.1, C304.1, L302.2, U301.C6 (VCCPLL1), U301.J6 (VCCPLL0)
unnamed: C301.1, C303.1, L301.2, U301.C10 (VPP_2V5)
unnamed: R303.2, U302.7 (~HOLD/~RESET/IO_{3})
unnamed: R304.2, U302.3 (~WP/IO_{2})

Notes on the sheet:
1-2 Program Flash 3-4
1-3 Program FPGA 2-4
Device Programming

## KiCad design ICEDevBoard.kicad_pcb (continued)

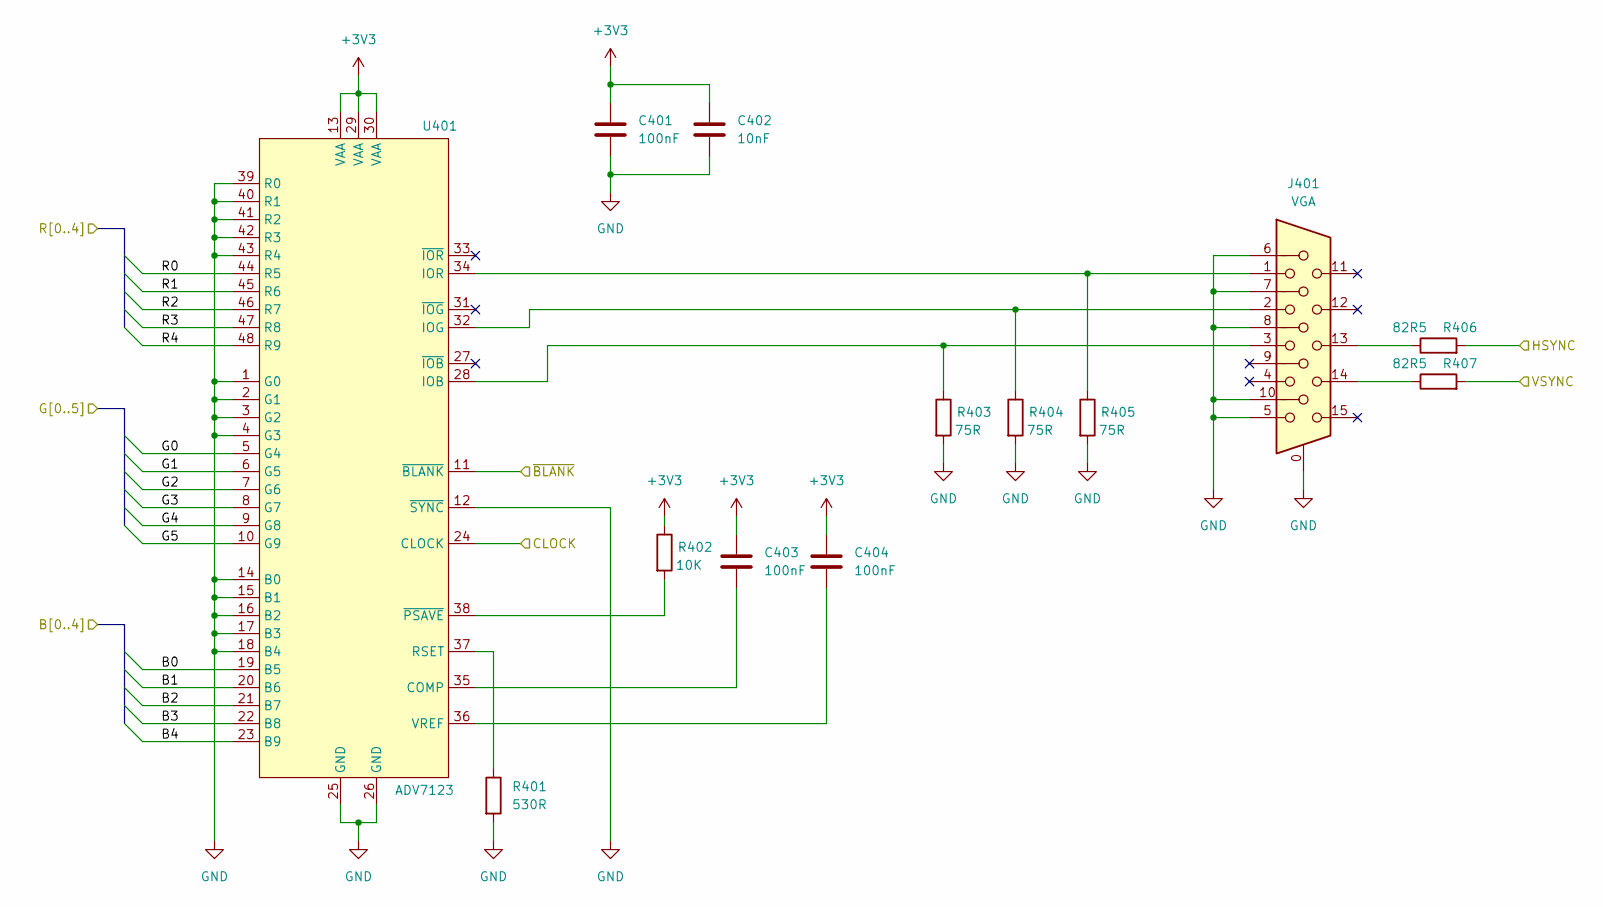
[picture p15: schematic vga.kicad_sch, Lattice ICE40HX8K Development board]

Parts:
C401, C403, C404: 100nF; C_0805_2012Metric
C402: 10nF; C_0805_2012Metric
J401: VGA; DSUB-15-HD_Socket_Horizontal_P2.29x2.54mm_EdgePinOffset8.35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
R401: 530R; R_0805_2012Metric
R402: 10K; R_0805_2012Metric
R403, R404, R405: 75R; R_0805_2012Metric
R406, R407: 82R5; R_0805_2012Metric
U401: ADV7123; LQFP-48_7x7mm_P0.5mm

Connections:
+3V3: C401.1, C402.1, C403.1, C404.1, R402.1, U401.13 (VAA), U401.29 (VAA), U401.30 (VAA); also elsewhere on the board
/FPGA/VGA_B0: U401.19 (B5); also elsewhere on the board
/FPGA/VGA_B1: U401.20 (B6); also elsewhere on the board
/FPGA/VGA_B2: U401.21 (B7); also elsewhere on the board
/FPGA/VGA_B3: U401.22 (B8); also elsewhere on the board
/FPGA/VGA_B4: U401.23 (B9); also elsewhere on the board
/FPGA/VGA_CLOCK: U401.24 (CLOCK); also elsewhere on the board
/FPGA/VGA_G0: U401.5 (G4); also elsewhere on the board
/FPGA/VGA_G1: U401.6 (G5); also elsewhere on the board
/FPGA/VGA_G2: U401.7 (G6); also elsewhere on the board
/FPGA/VGA_G3: U401.8 (G7); also elsewhere on the board
/FPGA/VGA_G4: U401.9 (G8); also elsewhere on the board
/FPGA/VGA_G5: U401.10 (G9); also elsewhere on the board
/FPGA/VGA_HSYNC: R406.2; also elsewhere on the board
/FPGA/VGA_R0: U401.44 (R5); also elsewhere on the board
/FPGA/VGA_R1: U401.45 (R6); also elsewhere on the board
/FPGA/VGA_R2: U401.46 (R7); also elsewhere on the board
/FPGA/VGA_R3: U401.47 (R8); also elsewhere on the board
/FPGA/VGA_R4: U401.48 (R9); also elsewhere on the board
/FPGA/VGA_VSYNC: R407.2; also elsewhere on the board
/FPGA/~VGA_BLANK: U401.11 (~BLANK); also elsewhere on the board
GND: C401.2, C402.2, J401.0, J401.5, J401.6, J401.7, J401.8, J401.10, R401.2, R403.2, R404.2, R405.2, U401.1 (G0), U401.2 (G1), U401.3 (G2), U401.4 (G3), U401.12 (~SYNC), U401.14 (B0), U401.15 (B1), U401.16 (B2), U401.17 (B3), U401.18 (B4), U401.25 (GND), U401.26 (GND), U401.39 (R0), U401.40 (R1), U401.41 (R2), U401.42 (R3), U401.43 (R4); also elsewhere on the board
unnamed: J401.13, R406.1
unnamed: J401.14, R407.1
unnamed: C403.2, U401.35 (COMP)
unnamed: J401.3, R403.1, U401.28 (IOB)
unnamed: J401.2, R404.1, U401.32 (IOG)
unnamed: J401.1, R405.1, U401.34 (IOR)
unnamed: R401.1, U401.37 (RSET)
unnamed: C404.2, U401.36 (VREF)
unnamed: R402.2, U401.38 (~PSAVE)

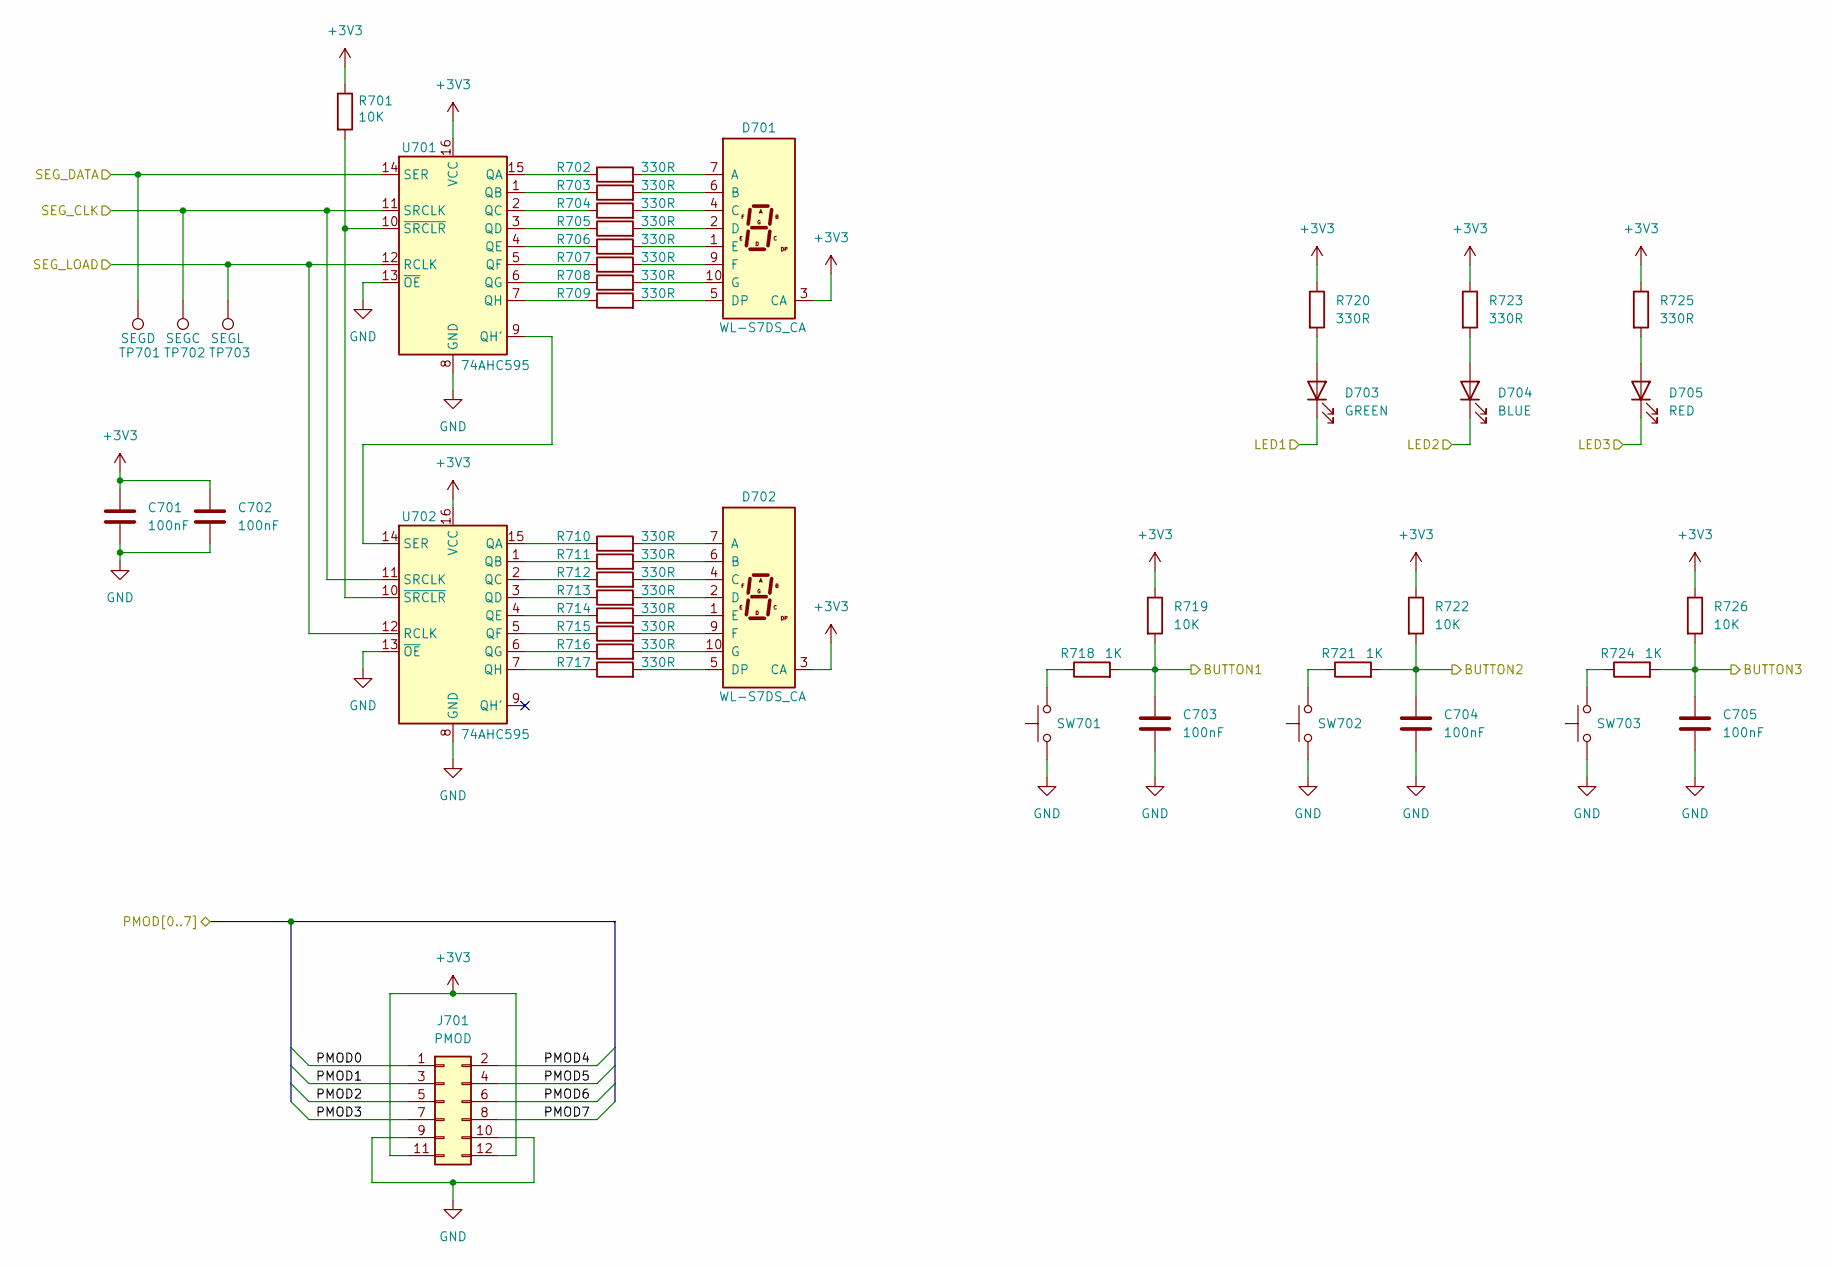
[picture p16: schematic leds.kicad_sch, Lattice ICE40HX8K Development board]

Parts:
C701, C702, C703, C704, C705: 100nF; C_0805_2012Metric
D701, D702: WL-S7DS_CA; WL-S7DS_0.3INCH
D703: GREEN; LED_1206_3216Metric
D704: BLUE; LED_1206_3216Metric
D705: RED; LED_1206_3216Metric
J701: PMOD; PinSocket_2x06_P2.54mm_Vertical
R701, R719, R722, R726: 10K; R_0805_2012Metric
R702, R703, R704, R705, R706, R707, R708, R709, R710, R711, R712, R713, R714, R715, R716, R717, R720, R723, R725: 330R; R_0805_2012Metric
R718, R721, R724: 1K; R_0805_2012Metric
SW701, SW702, SW703: SW_Push; SW_PUSH_6mm_H4.3mm
TP701: SEGD; TestPoint_Pad_D1.0mm
TP702: SEGC; TestPoint_Pad_D1.0mm
TP703: SEGL; TestPoint_Pad_D1.0mm
U701, U702: 74AHC595; SO-16_3.9x9.9mm_P1.27mm

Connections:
+3V3: C701.1, C702.1, D701.3 (CA), D702.3 (CA), J701.11, J701.12, R701.1, R719.1, R720.1, R722.1, R723.1, R725.1, R726.1, U701.16 (VCC), U702.16 (VCC); also elsewhere on the board
/FPGA/BUTTON1: C703.1, R718.2, R719.2; also elsewhere on the board
/FPGA/BUTTON2: C704.1, R721.2, R722.2; also elsewhere on the board
/FPGA/BUTTON3: C705.1, R724.2, R726.2; also elsewhere on the board
/FPGA/LED1: D703.1 (K); also elsewhere on the board
/FPGA/LED2: D704.1 (K); also elsewhere on the board
/FPGA/LED3: D705.1 (K); also elsewhere on the board
/FPGA/PMOD0: J701.1; also elsewhere on the board
/FPGA/PMOD1: J701.3; also elsewhere on the board
/FPGA/PMOD2: J701.5; also elsewhere on the board
/FPGA/PMOD3: J701.7; also elsewhere on the board
/FPGA/PMOD4: J701.2; also elsewhere on the board
/FPGA/PMOD5: J701.4; also elsewhere on the board
/FPGA/PMOD6: J701.6; also elsewhere on the board
/FPGA/PMOD7: J701.8; also elsewhere on the board
/FPGA/SEG_CLK: TP702.1, U701.11 (SRCLK), U702.11 (SRCLK); also elsewhere on the board
/FPGA/SEG_DATA: TP701.1, U701.14 (SER); also elsewhere on the board
/FPGA/SEG_LOAD: TP703.1, U701.12 (RCLK), U702.12 (RCLK); also elsewhere on the board
GND: C701.2, C702.2, C703.2, C704.2, C705.2, J701.9, J701.10, SW701.2, SW702.2, SW703.2, U701.8 (GND), U701.13 (~OE), U702.8 (GND), U702.13 (~OE); also elsewhere on the board
unnamed: D701.7 (A), R702.2
unnamed: D701.6 (B), R703.2
unnamed: D701.4 (C), R704.2
unnamed: D701.2 (D), R705.2
unnamed: D701.5 (DP), R709.2
unnamed: D701.1 (E), R706.2
unnamed: D701.9 (F), R707.2
unnamed: D701.10 (G), R708.2
unnamed: D702.7 (A), R710.2
unnamed: D702.6 (B), R711.2
unnamed: D702.4 (C), R712.2
unnamed: D702.2 (D), R713.2
unnamed: D702.5 (DP), R717.2
unnamed: D702.1 (E), R714.2
unnamed: D702.9 (F), R715.2
unnamed: D702.10 (G), R716.2
unnamed: D703.2 (A), R720.2
unnamed: D704.2 (A), R723.2
unnamed: D705.2 (A), R725.2
unnamed: R718.1, SW701.1
unnamed: R721.1, SW702.1
unnamed: R724.1, SW703.1
unnamed: R702.1, U701.15 (QA)
unnamed: R703.1, U701.1 (QB)
unnamed: R704.1, U701.2 (QC)
unnamed: R705.1, U701.3 (QD)
unnamed: R706.1, U701.4 (QE)
unnamed: R707.1, U701.5 (QF)
unnamed: R708.1, U701.6 (QG)
unnamed: U701.9 (QH'), U702.14 (SER)
unnamed: R709.1, U701.7 (QH)
unnamed: R701.2, U701.10 (~SRCLR), U702.10 (~SRCLR)
unnamed: R710.1, U702.15 (QA)
unnamed: R711.1, U702.1 (QB)
unnamed: R712.1, U702.2 (QC)
unnamed: R713.1, U702.3 (QD)
unnamed: R714.1, U702.4 (QE)
unnamed: R715.1, U702.5 (QF)
unnamed: R716.1, U702.6 (QG)
unnamed: R717.1, U702.7 (QH)

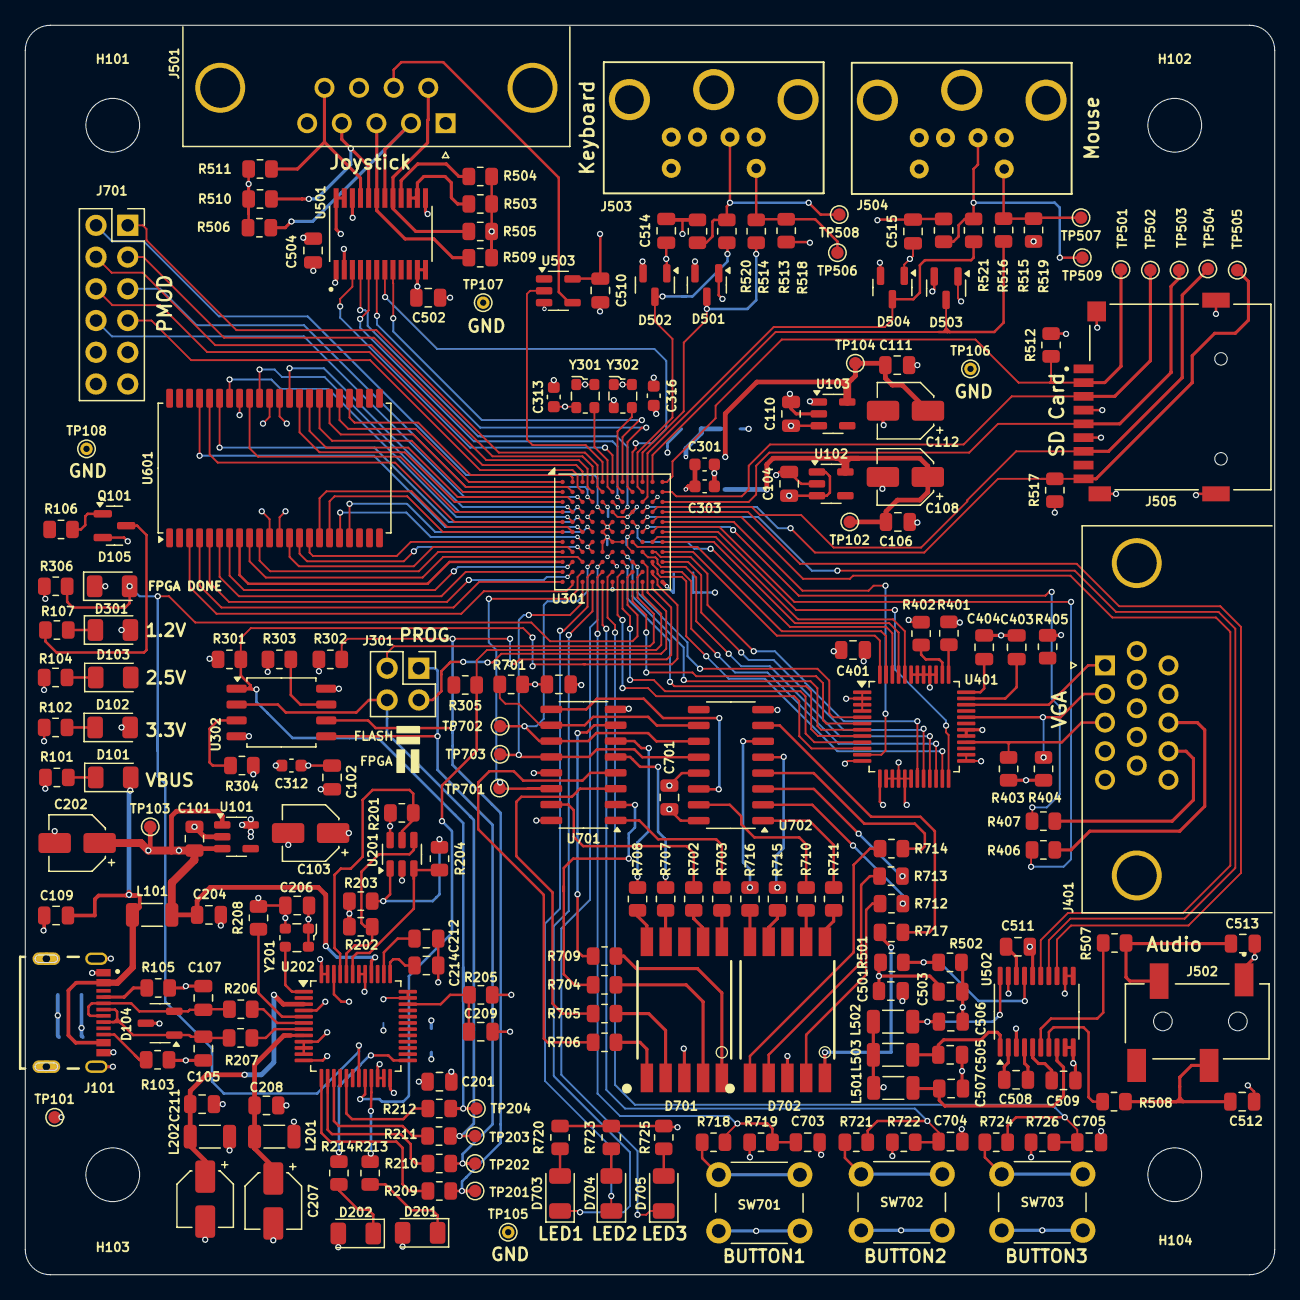
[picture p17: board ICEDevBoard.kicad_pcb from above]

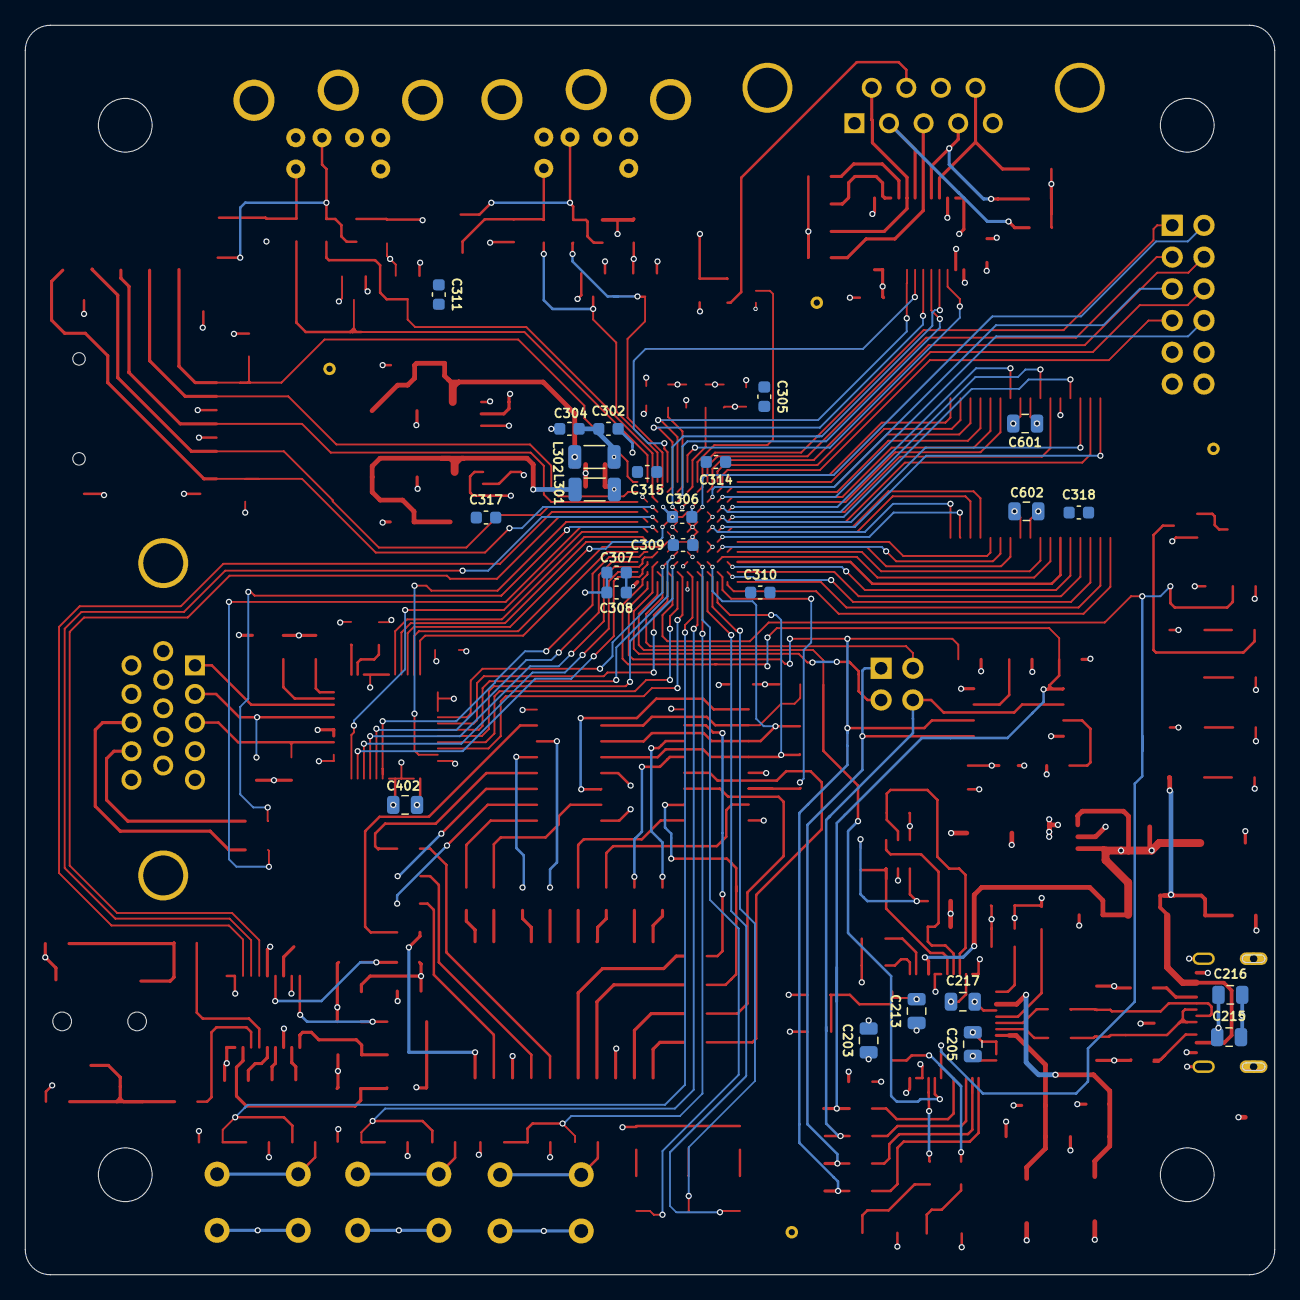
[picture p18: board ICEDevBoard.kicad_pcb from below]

Board: 4 copper layers, 100.0 x 100.0 mm, 237 parts (24 on the bottom side), 209 nets.

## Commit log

2025-04-26 Initial schematic design
    [BAT-HLD-001.step, CLV1L-FKB-CJ1N1E1BB7B3B3.stp, EXB-S8V391J.stp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]
2025-05-03 Started layout
    [ICEDevBoard.kicad_pcb, ICEDevBoard.kicad_sch]
2025-05-03 Working on board layout
    [ICEDevBoard.kicad_pcb, ICEDevBoard.kicad_sch, fpga.kicad_sch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]
2025-05-03 More board layout
    [ECS-2520MV-120-BL-TR.STEP, ICEDevBoard.kicad_pcb, ICEDevBoard.kicad_sch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]
2025-05-03 Started FPGA fanout
    [ICEDevBoard.kicad_pcb, fpga.kicad_sch, leds.kicad_sch]
2025-05-03 Updated constraints
    [ICEDevBoard.kicad_pcb]
2025-05-04 All pins fed out of FPGA
    [ICEDevBoard.kicad_pcb]
2025-05-05 Working on layout
    [ICEDevBoard.kicad_pcb]
2025-05-05 Initial FPGA layout done
    [ICEDevBoard.kicad_pcb, fpga.kicad_sch]
2025-05-05 Started board routing
    [ICEDevBoard.kicad_pcb, fpga.kicad_sch]
2025-05-06 Routed SRAM
    [ICEDevBoard.kicad_pcb, fpga.kicad_sch]
2025-05-07 Additional routing
    [ICEDevBoard.kicad_pcb, fpga.kicad_sch]
2025-05-07 More layout done
    [ICEDevBoard.kicad_pcb, fpga.kicad_sch]
2025-05-14 More layout changes
    [ICEDevBoard.kicad_pcb]
2025-05-14 Reworking layout
    [ICEDevBoard.kicad_pcb, programming.kicad_sch]
2025-05-16 Latest changes
    [ICEDevBoard.kicad_pcb, ICEDevBoard.kicad_sch]
